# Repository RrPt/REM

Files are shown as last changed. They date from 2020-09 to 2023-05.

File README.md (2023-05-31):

# REM
Rainers Energy Measurement

**Short englisch description:**  
*REM is an AC Energy Monitor based on the Analog Devices IC ADE7816 and a 
ESP32 microcontroller. It consists of one controlling module REM-C and one
to eight measuring modules REM-M, where each REM-M modul can measure up to 
12 different circuits. So totaly 96 circuits can be meassured.
Power data can be sent by MQTT or WebServer. The Webserver ist also used for configuration and calibration.*

*This project ist in german, to translate you can use a translator program like [here](https://translate.google.com/translate?hl=de&sl=auto&tl=en&u=https%3A%2F%2Fgithub.com%2FRrPt%2FREM)*

**Kurzbeschreibung:**  
REM ist ein Energiemonitor der auf dem Analog Device IC ADE7816 und einem Mikrocontroller ESP32 basiert.
Er besteht aus einem Kontrollermodul REM-C und einem bis acht Messmodulen REM-M. 
Jedes REM-M Modul kann 12 verschiedene Leistungskreise messen, so dass insgesamt bis zu 
96 Schaltkreise gemessen werden können.
Die Leistungsdaten können per MQTT versendet oder über einen Webserver abgefragt werden.
Der Webserver wird auch für die Konfiguration und die Kalibrierung verwendet.

Die Komponenten werden normalerweise in der Hausverteilung installiert und können dann die Leistung von z.B. einzelnen Zimmern erfassen.

Wine ausführliche Beschreibung ist im [Wiki](../../wiki/Home) zu finden.
## Übersicht
Das System besteht aus mehreren Hutschinenkomponenten, die über den REM-Bus miteinander verbunden sind
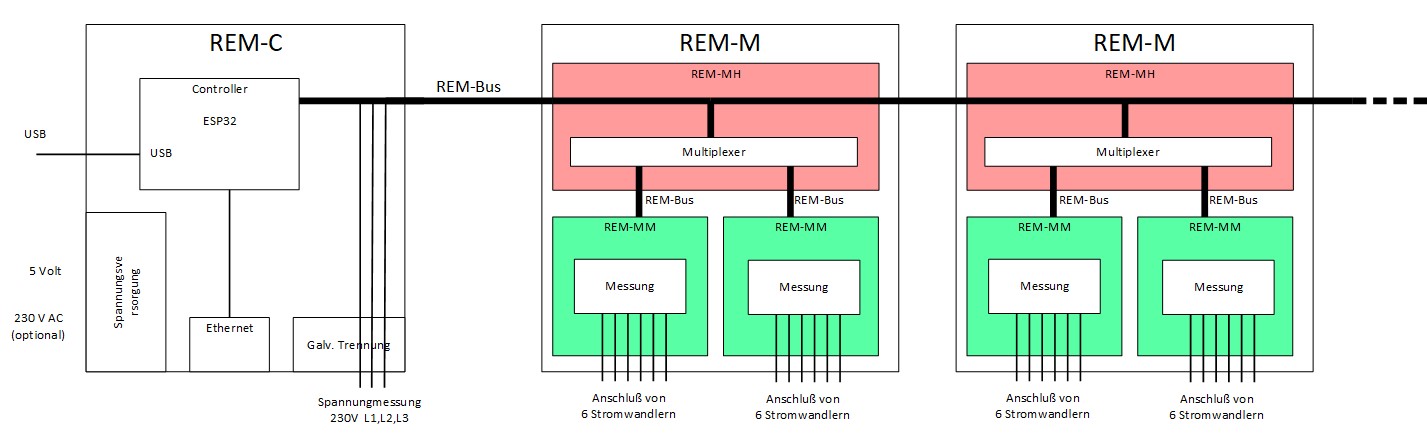
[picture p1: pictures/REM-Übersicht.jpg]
REM Übersicht


## [REM-C](../../wiki/REM-C) 
Das REM-C Modul enthält den Controller. Dieser fragt alle Messwerte über den 
REM-Bus von den einzelnen REM-M Modulen ab und stellt diesen über den 
Ethernetanschluß zur Verfügung. Die geschieht per MQTT und einen Webserver.
Über den Webserver erfolgt auch die Kalibrierung.

An das REM-C Modul werden auch die drei Phasen der Spannungssignale angeschlossen,
diese werden galvanisch getrennt und über den REM-Bus den einzelnen REM-M Modulen
 zur Verfügung gestellt.

Es können bis zu 8 REM-M Module mit je 12 Kanälen angeschlossen werden, 
insgesamt also bis zu 96 Kanäle.

Für die Platine des REM-C Moduls stehen die KICAD Pläne, 
die 3D-Modelle der Gehäuse (SCAD) und 
die Controllersoftware in C++ (Arduino) zur Verfügung. 

## [REM-M](../../wiki/REM-M) 
### [REM-MH](https://github.com/RrPt/REM/wiki/REM-MH) 
Das REM-M Modul beinhaltet zum einen ein Verteilermodul REM-MH, 
welches den REM-BUS auf die 2 REM-MM Module aufteilt.
Auf diesem wird auch per Jumper die Adresse des REM-M Moduls eingestellt.
### [REM-MM](../../wiki/REM-MM) 
Jedes REM-M Modul beinhaltet 2 REM-MM Platinen, die für die eigentliche 
Messung zuständig sind.
An jede REM-MM Platine können 6 Stromsensoren angeschlossen werden, 
zusammen mit der über den REM-Bus gelieferten Spannung 
(Phase über Jumper für alle 6 Sensoren gleich einstellbar)
können so für alle 6 Kanäle die folgenden Energieparameter bestimmt werden:
 * Strom RMS
 * Leistung
 * Blindleistung
 
Pro REM-MM Platine:
 * Spannung RMS
 * Frequenz

Für die Platinen des REM-M Moduls stehen die KICAD Pläne und 
die 3D-Modelle der Gehäuse (SCAD) zur Verfügung. 

## Status
Das Projekt ist fertiggestellt und bei mir seit Anfang 2021 ununterbrochen ohne Probleme im Betrieb.

## Bilder

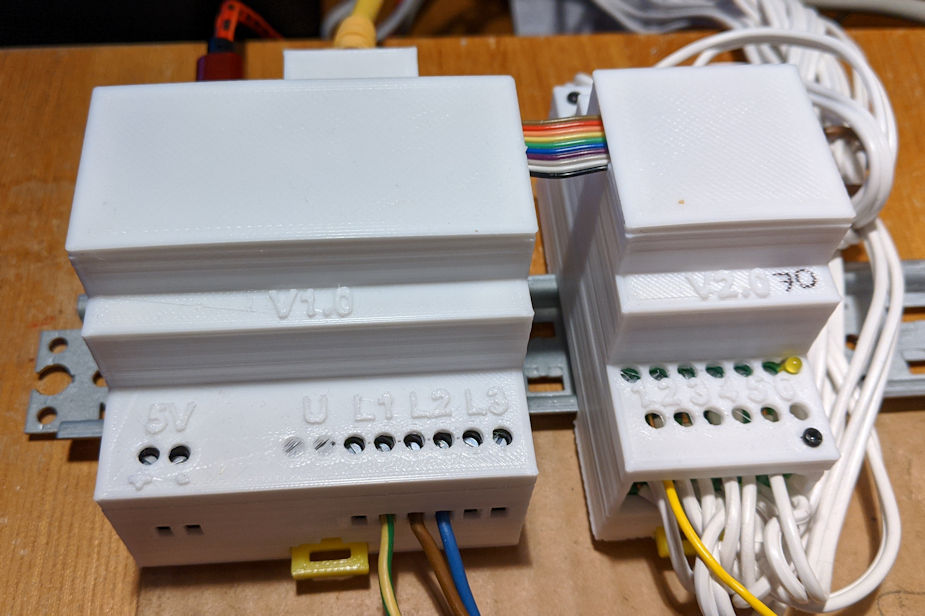
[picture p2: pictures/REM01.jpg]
REM01


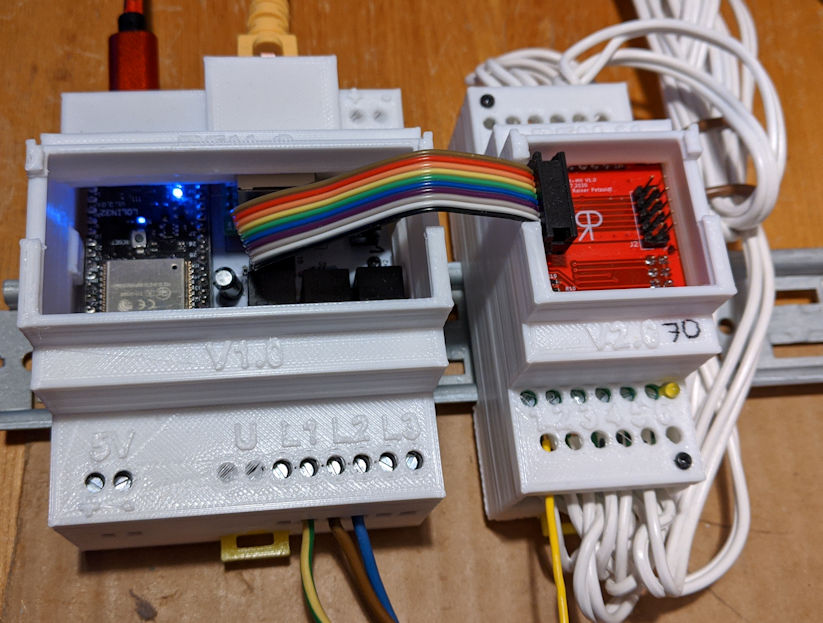
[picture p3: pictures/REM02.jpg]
REM02


## Stichwörter
 * ADE7816, Energy Metering IC
 * ESP32
 * TCA9548A
 * USR ES1
 * Leistungsmessung, Blindleistungsmessung, Spannungsmessung, Strommessung, RMS
 * Stromwandler, Current transformer, ZMPT107-1, CT1005
 * Energiemonitor

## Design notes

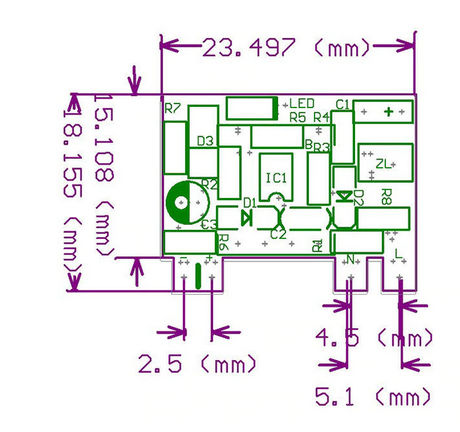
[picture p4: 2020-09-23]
REM-Platinen/3d/acad/Skizze.jpg

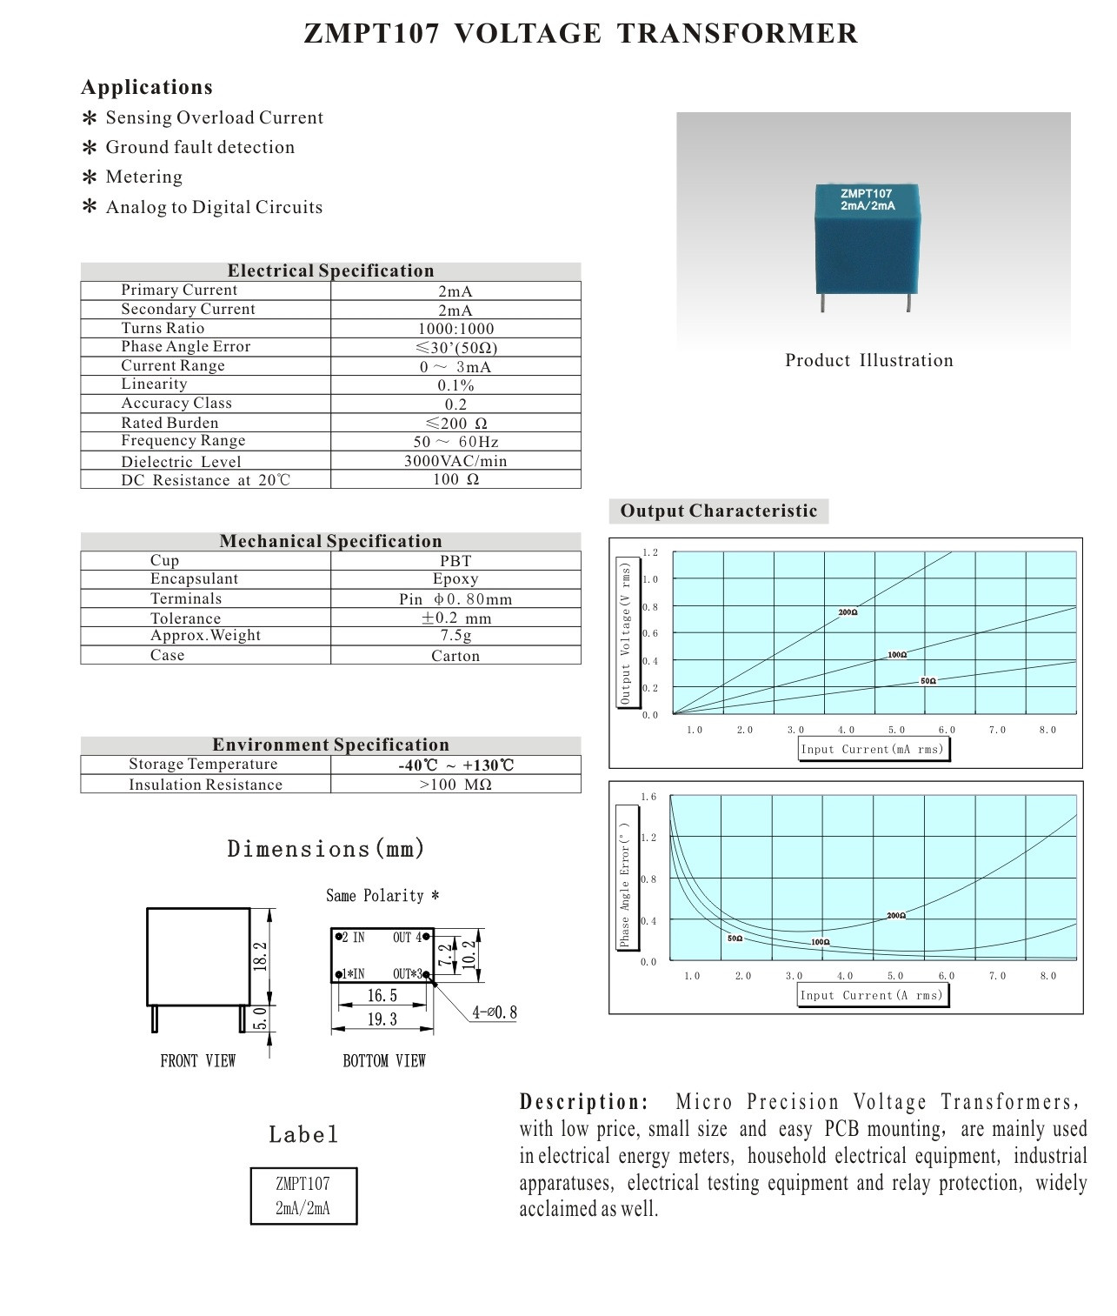
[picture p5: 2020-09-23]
REM-Platinen/Bauteile/ZMPT107.jpg

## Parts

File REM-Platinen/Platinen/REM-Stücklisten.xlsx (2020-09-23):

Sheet: REM-C
Reference | Quantity | Value | Footprint | Datasheet | Preis | Link | Lieferant | Summe
C1 C3 C4 C5 | 4 | 100n | Capacitor_SMD:C_0603_1608Metric | https://cdn-reichelt.de/documents/datenblatt/B300/KEM_C0XXX_Y5V_DB-EN.pdf | 0.02 | https://www.reichelt.de/vielschicht-kerko-100nf-25v-85-c-kem-y5v0603-100n-p207005.html | Reichelt | 0.08 €
C2 C6 | 2 | 10u | Capacitor_THT:CP_Radial_D5.0mm_P2.00mm | https://cdn-reichelt.de/documents/datenblatt/B300/KEM_C0XXX_X7R_DB-EN.pdf | 0.1 | https://www.reichelt.de/elko-radial-10-uf-50-v-105-c-low-esr-fr-a-10u-50-p200268.html | Reichelt | 0.20 €
J4 J3 J2 J1 J5 J6 | 6 | Conn_01x02 | REM:W237-102 | https://cdn-reichelt.de/documents/datenblatt/C100/AKL073%23RIA.pdf | 0.5 | https://www.reichelt.de/fahrstuhlklemme-2-pol-4-mm-rm-5-08-akl-073-02-p36620.html | Reichelt | 3.00 €
J7 | 1 | Conn_02x05_Odd_Even | REM:PinHeader_2x05_P2.54mm_Vertical_mit_Stecker | https://cdn-reichelt.de/documents/datenblatt/C140/DS_MPE_087.pdf | 0.23 | https://www.reichelt.de/stiftleisten-2-54-mm-2x05-gerade-mpe-087-2-010-p119895.html | Reichelt | 0.23 €
PS1 | 1 | AC-DC-Wandler | REM:AC-DC_Wandler |  | 1.31 | https://de.aliexpress.com/item/33030791040.html | AliExpress | 1.31 €
R1 R3 R2 | 3 | 220k | Resistor_THT:R_Axial_DIN0414_L11.9mm_D4.5mm_P15.24mm_Horizontal | https://www.reichelt.de/index.html?ACTION=7&LA=3&OPEN=0&INDEX=0&FILENAME=B300%2FNHMBX-SMA_DATA_EN.pdf | 0.13 | https://www.reichelt.de/duennschichtwiderstand-axial-1-w-220-kohm-1-vi-mbe04140c2203-p233820.html | Reichelt | 0.39 €
R6 R5 R4 | 3 | 330 | Resistor_THT:R_Axial_DIN0207_L6.3mm_D2.5mm_P7.62mm_Horizontal | https://cdn-reichelt.de/documents/datenblatt/B300/NGMBX-SMA_DATA_E.pdf | 0.04 | https://www.reichelt.de/duennschichtwiderstand-axial-0-6-w-330-ohm-1-vi-mbb02070c3300-p233724.html | Reichelt | 0.12 €
T3 T2 T1 | 3 | ZMPT107-1 | REM:ZMPT107 | D:\Daten\Petzoldt\Rainer\Entwicklung\REM\Bauteile\ZMPT101B specification.pdf | 0.95 | https://de.aliexpress.com/item/10000007567815.html | AliExpress | 2.85 €
U1 | 1 | Lolin32 | REM:Lolin32 |  | 3.61 | https://de.aliexpress.com/item/4000340140634.html | AliExpress | 3.61 €
U2 | 1 | USR-ES1 | REM:USR-ES1 | D:\Daten\Petzoldt\Rainer\Entwicklung\Dokumentation\Bauteiledokumentation\Adapter\USR-ES1-EN-V1.0.pdf | 3.33 | https://de.aliexpress.com/item/4000923964703.html | AliExpress | 3.33 €
ESP32-Fassung | 1 | 16 | 16 | https://cdn-reichelt.de/documents/datenblatt/C140/DATENBLATT_B01-EBLG70_DB.pdf | 0.84 | https://www.reichelt.de/buchsenleiste-16-pol-gerade-rm-2-54-h-7-0-mm-bl-1x16g7-2-54-p180555.html | Reichelt | 0.84 €
ESP32-Fassung | 1 | 20 | 20 | https://cdn-reichelt.de/documents/datenblatt/C140/DATENBLATT_B01-EBLG70_DB.pdf | 0.99 | https://www.reichelt.de/20pol-buchsenleiste-gerade-rm-2-54-h-7-0mm-bl-1x20g7-2-54-p73677.html | Reichelt | 0.99 €
USR-Fassung | 2 | 6 | 1 x 6 | https://cdn-reichelt.de/documents/datenblatt/C140/DATENBLATT_B01-EBLG70_DB.pdf | 0.31 | https://www.reichelt.de/buchsenleiste-6-pol-gerade-rm-2-54-h-7-0-mm-bl-1x06g7-2-54-p180550.html | Reichelt | 0.62 €
 | 1 | 2 x 5 | IDC-Federleiste 10P | https://cdn-reichelt.de/documents/datenblatt/C150/RND_205-00682_ENG_TDS.pdf | 0.25 € | https://www.reichelt.de/idc-federleiste-10p-rnd-205-00682-p222827.html | Reichelt | 0.25 €
 |  |  |  |  |  | Summe |  | 17.82 €

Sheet: REM-MH
Reference | Quantity | Value | Footprint | Datasheet | Preis | Link | Lieferant | Summe
C7 C1 | 2 | 10u | Capacitor_SMD:C_1206_3216Metric | https://cdn-reichelt.de/documents/datenblatt/B300/KEM_C0XXX_X7R_DB-EN.pdf | 0.13 | https://www.reichelt.de/vielschicht-kerko-10-f-16v-125-c-kem-x7r1206-10u-p207163.html? | Reichelt | 0.26 €
C8 C2 | 2 | 220n | Capacitor_SMD:C_0603_1608Metric | https://cdn-reichelt.de/documents/datenblatt/A900/RND_1398195_CAP_0603_X7R_ENG_TDS.pdf | 0.02 | https://www.reichelt.de/smd-kerko-0603-220-nf-16-v-10-mlcc-rnd-150sh18b224-p225500.html | Reichelt | 0.04 €
J3 J4 J1 J2 | 4 | Conn_02x05_Odd_Even | REM:PinHeader_2x05_P2.54mm_Vertical_mit_Stecker | https://cdn-reichelt.de/documents/datenblatt/C140/DS_MPE_087.pdf | 0.23 € | https://www.reichelt.de/stiftleisten-2-54-mm-2x05-gerade-mpe-087-2-010-p119895.html | Reichelt | 0.92 €
J5 | 1 | Conn_02x03_Odd_Even | Connector_PinHeader_2.54mm:PinHeader_2x03_P2.54mm_Vertical | https://cdn-reichelt.de/documents/datenblatt/C140/RND_205-00634_DB_EN.pdf | 0.03 | https://www.reichelt.de/rnd-stiftleiste-6-pol-rm-2-54-mm-rnd-205-00634-p208860.html?&trstct=pol_0 | Reichelt | 0.03 €
R1 R2 R3 R4 R6 R7 R8 R5 | 8 | 10k | Resistor_SMD:R_0603_1608Metric | https://cdn-reichelt.de/documents/datenblatt/B300/RND_SMD_0603_RESISTOR_2017.pdf | 0.02 | https://www.reichelt.de/smd-widerstand-0603-10-kohm-100-mw-1-vis-crcw060310k-p238029.html | Reichelt | 0.16 €
U1 | 1 | TCA9548APWR | Package_SO:TSSOP-24_4.4x7.8mm_P0.65mm | http://www.ti.com/lit/ds/symlink/tca9548a.pdf | 1.37 | https://www.digikey.de/product-detail/de/texas-instruments/TCA9548APWR/296-34905-1-ND/3615448 | DigiKey | 1.37 €
 | 4 | 2 x 5 | IDC-Federleiste 10P | https://cdn-reichelt.de/documents/datenblatt/C150/RND_205-00682_ENG_TDS.pdf | 0.25 € | https://www.reichelt.de/idc-federleiste-10p-rnd-205-00682-p222827.html | Reichelt | 1.00 €
 |  |  |  |  |  | Summe |  | 3.78 €

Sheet: REM-MM
Reference | Quantity | Value | Footprint | Datasheet | Preis | Link | Lieferant | Summe
C11 C17 C9 C8 | 4 | 220n | Capacitor_SMD:C_0603_1608Metric | https://cdn-reichelt.de/documents/datenblatt/A900/RND_1398195_CAP_0603_X7R_ENG_TDS.pdf | 0.02 € | https://www.reichelt.de/smd-kerko-0603-220-nf-25-v-10-mlcc-rnd-1500603x224-p226196.html | Reichelt | 0.08 €
C12 C10 C18 | 3 | 4.7u | Capacitor_SMD:C_1206_3216Metric | https://cdn-reichelt.de/documents/datenblatt/B300/RND_1206_ENG_TDS.pdf | 0.08 € | https://www.reichelt.de/smd-kerko-1206-4-7-f-50-v-10-mlcc-rnd-1501206b475k-p254230.html | Reichelt | 0.24 €
C13 C2 C3 C4 C5 C6 C1 | 7 | 22n | Capacitor_SMD:C_0603_1608Metric | ~ | 0.02 € | https://www.reichelt.de/smd-vielschicht-keramikkondensator-22n-10-x7r-g0603-22n-p31871.html | Reichelt | 0.14 €
C14 | 1 | 1u | Capacitor_SMD:C_0603_1608Metric | https://cdn-reichelt.de/documents/datenblatt/A900/RND_1407500_CAP_0603_NP0_ENG_TDS.pdf | 0.02 € | https://www.reichelt.de/smd-kerko-0603-6-8-pf-16-v-10-mlcc-rnd-150mt18n6r81-p225486.html | Reichelt | 0.02 €
C15 C16 | 2 | 20p | Capacitor_SMD:C_0603_1608Metric | https://cdn-reichelt.de/documents/datenblatt/B300/KEM_C0XXX_C0G_DB-EN.pdf | 0.03 € | https://www.reichelt.de/vielschicht-kerko-20pf-50v-125-c-kem-c0g0603-20p-p206942.html | Reichelt | 0.06 €
C7 | 1 | 10u | Capacitor_SMD:C_1206_3216Metric | https://cdn-reichelt.de/documents/datenblatt/B300/KEM_C0XXX_X7R_DB-EN.pdf | 0.13 € | https://www.reichelt.de/vielschicht-kerko-10-f-16v-125-c-kem-x7r1206-10u-p207163.html? | Reichelt | 0.13 €
J1 | 1 | Conn_02x05_Odd_Even | REM:PinHeader_2x05_P2.54mm_Vertical_mit_Stecker | https://cdn-reichelt.de/documents/datenblatt/C140/DS_MPE_087.pdf | 0.23 € | https://www.reichelt.de/stiftleisten-2-54-mm-2x05-gerade-mpe-087-2-010-p119895.html | Reichelt | 0.23 €
J2 | 1 | Conn_02x03_Odd_Even | Connector_PinHeader_2.54mm:PinHeader_2x03_P2.54mm_Vertical | https://cdn-reichelt.de/documents/datenblatt/C140/RND_205-00634_DB_EN.pdf | 0.03 € | https://www.reichelt.de/rnd-stiftleiste-6-pol-rm-2-54-mm-rnd-205-00634-p208860.html?&trstct=pol_0 | Reichelt | 0.03 €
J3 | 1 | DG127A 5,08-6 | REM:pxc_1726189_05_MKKDSN-1-5-6-5-08 | https://www.reichelt.de/index.html?ACTION=7&LA=3&OPEN=0&INDEX=0&FILENAME=C151%2FDG127A.pdf | 0.99 € | https://www.reichelt.de/leiterplattenklemme-6-polig-rm-5-08-mm-dg127a-5-08-6-p276159.html? | Reichelt | 0.99 €
R11 R12 R13 R14 R15 R16 | 6 | 47 | Resistor_SMD:R_0603_1608Metric | https://cdn-reichelt.de/documents/datenblatt/B400/DS_PAN_SERIE_ERA.pdf | 0.25 € | https://www.reichelt.de/smd-widerstand-0603-47-0-ohm-100-mw-0-1-spr-0603-47-0-p123052.html | Reichelt | 1.50 €
R7 R1 R2 R3 R4 R5 R6 | 7 | 1k | Resistor_SMD:R_0603_1608Metric | https://cdn-reichelt.de/documents/datenblatt/B300/RND_SMD_0603_RESISTOR_2017.pdf | 0.02 € | https://www.reichelt.de/smd-widerstand-0603-1-0-kohm-100-mw-1-rnd-0603-1-1-0k-p183054.html | Reichelt | 0.14 €
R8 | 1 | 4.7M | Resistor_SMD:R_0603_1608Metric | https://cdn-reichelt.de/documents/datenblatt/B300/RND_SMD_0603_RESISTOR_2017.pdf | 0.02 € | https://www.reichelt.de/smd-widerstand-0603-4-7-mohm-100-mw-1-rnd-0603-1-4-7m-p183143.html | Reichelt | 0.02 €
R9 | 1 | 10k | Resistor_SMD:R_0603_1608Metric | https://cdn-reichelt.de/documents/datenblatt/B300/RND_SMD_0603_RESISTOR_2017.pdf | 0.02 € | https://www.reichelt.de/smd-widerstand-0603-10-kohm-100-mw-1-vis-crcw060310k-p238029.html | Reichelt | 0.02 €
U1 | 1 | ADE7816ACPZ | REM:QFN50P600X600X80-41N | https://www.analog.com/media/en/technical-documentation/data-sheets/ADE7816.pdf | 10.20 € | https://www.digikey.de/product-detail/de/analog-devices-inc/ADE7816ACPZ/ADE7816ACPZ-ND/3131705 | DigiKey | 10.20 €
U2 | 1 | MCP23008-xSO | Package_SO:SOIC-18W_7.5x11.6mm_P1.27mm | http://ww1.microchip.com/downloads/en/DeviceDoc/MCP23008-MCP23S08-Data-Sheet-20001919F.pdf | 0.94 € | https://www.digikey.de/product-detail/de/microchip-technology/MCP23008T-E-SO/MCP23008T-E-SOCT-ND/5358243 | DigiKey | 0.94 €
Y1 | 1 | 16.384MHz | Crystal:Crystal_SMD_2520-4Pin_2.5x2.0mm | https://support.epson.biz/td/api/doc_check.php?dl=brief_FA-238&lang=en | 0.30 € | https://www.digikey.de/products/de/crystals-oscillators-resonators/crystals/171?k=quarz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 | DigiKey | 0.30 €
 | 1 | 2 x 5 | IDC-Federleiste 10P | https://cdn-reichelt.de/documents/datenblatt/C150/RND_205-00682_ENG_TDS.pdf | 0.25 € | https://www.reichelt.de/idc-federleiste-10p-rnd-205-00682-p222827.html | Reichelt | 0.25 €
 |  |  |  |  |  | Summe |  | 15.29 €

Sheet: Reichelt
 |  |  |  |  | 3 | 5 | 10 |  |  |  |  |  | Nachbestellung 9.8.20
Reference | Value | Einzelpreis | Link | Lieferant | REM-C | REM-MH | REM-MM | Anzahl | Preis | Bestellmenge | Preis | Anz Reserve | Bestellmenge | Preis | Anz Reserve | Bestand 9.8
C | 100n | 0.02 € | https://www.reichelt.de/vielschicht-kerko-100nf-25v-85-c-kem-y5v0603-100n-p207005.html | Reichelt | 4 |  |  | 12 | 0.24 € | 10 | 0.20 € | -2 | 50 | 1.00 € | 48 | 6
C | 10u | 0.10 € | https://www.reichelt.de/elko-radial-10-uf-50-v-105-c-low-esr-fr-a-10u-50-p200268.html | Reichelt | 2 |  |  | 6 | 0.60 € | 5 | 0.50 € | -1 | 10 | 1.00 € | 9 | 3
C | 10u | 0.13 € | https://www.reichelt.de/vielschicht-kerko-10-f-16v-125-c-kem-x7r1206-10u-p207163.html? | Reichelt |  | 2 | 1 | 20 | 2.60 € | 20 | 2.60 € | 0 | 10 | 1.30 € | 10 | 14
C | 1u | 0.08 € | https://www.reichelt.de/smd-vielschichtkondensator-g0603-1-0-f-16v-x7r-g0603-1-0-16-p89719.html | Reichelt | 1 |  | 1 | 13 | 1.04 € | 20 | 1.60 € | 7 | 20 | 1.60 € | 27 | 15
C | 20p | 0.03 € | https://www.reichelt.de/vielschicht-kerko-20pf-50v-125-c-kem-c0g0603-20p-p206942.html | Reichelt |  |  | 2 | 20 | 0.60 € | 20 | 0.60 € | 0 | 20 | 0.60 € | 20 | 12
C | 220n | 0.02 € | https://www.reichelt.de/smd-kerko-0603-220nf-10v-10-mlcc-ft-cap-x7r-0603fcc-220n-p193817.html | Reichelt |  | 2 | 4 | 50 | 1.00 € | 50 | 1.00 € | 0 | 50 | 1.00 € | 50 | 36
C | 22n | 0.02 € | https://www.reichelt.de/smd-vielschicht-keramikkondensator-22n-10-x7r-g0603-22n-p31871.html | Reichelt |  |  | 7 | 70 | 1.40 € | 70 | 1.40 € | 0 | 50 | 1.00 € | 50 | 36
C | 4.7u | 0.08 € | https://www.reichelt.de/smd-kerko-1206-4-7-f-50-v-10-mlcc-rnd-1501206b475k-p254230.html | Reichelt |  |  | 3 | 30 | 2.40 € | 30 | 2.40 € | 0 | 20 | 1.60 € | 20 | 18
ESP32-Fassung | 16 | 0.84 € | https://www.reichelt.de/buchsenleiste-16-pol-gerade-rm-2-54-h-7-0-mm-bl-1x16g7-2-54-p180555.html | Reichelt | 1 |  |  | 3 | 2.52 € | 5 | 4.20 € | 2 | 3 | 2.52 € | 5 | 4
ESP32-Fassung | 20 | 0.99 € | https://www.reichelt.de/20pol-buchsenleiste-gerade-rm-2-54-h-7-0mm-bl-1x20g7-2-54-p73677.html | Reichelt | 1 |  |  | 3 | 2.97 € | 5 | 4.95 € | 2 | 3 | 2.97 € | 5 | 4
J3 | DG127A 5,08-6 | 0.99 € | https://www.reichelt.de/leiterplattenklemme-6-polig-rm-5-08-mm-dg127a-5-08-6-p276159.html? | Reichelt |  |  | 2 | 20 | 19.80 € | 10 | 9.90 € | -10 | 15 | 14.85 € | 5 | 2
J4 J3 J2 J1 J5 J6 | AKL 073-02 | 0.50 € | https://www.reichelt.de/fahrstuhlklemme-2-pol-4-mm-rm-5-08-akl-073-02-p36620.html | Reichelt | 6 |  |  | 18 | 9.00 € | 15 | 7.50 € | -3 | 10 | 5.00 € | 7 | 11
J5 | Conn_02x03_Odd_Even | 0.03 € | https://www.reichelt.de/rnd-stiftleiste-6-pol-rm-2-54-mm-rnd-205-00634-p208860.html?&trstct=pol_0 | Reichelt |  | 1 | 1 | 15 | 0.45 € | 15 | 0.45 € | 0 | 10 | 0.30 € | 10 | 10
J7 | Conn_02x05_Odd_Even | 0.03 € | https://www.reichelt.de/rnd-stiftleiste-10-pol-rm-2-54-mm-rnd-205-00636-p208862.html | Reichelt | 1 | 4 | 1 | 33 | 0.99 € | 30 | 0.90 € | -3 | 20 | 0.60 € | 17 | 21
 | Conn_02x06_Odd_Even | 0.04 € | https://www.reichelt.de/rnd-stiftleiste-12-pol-rm-2-54-mm-rnd-205-00637-p208863.html | Reichelt | 1 |  |  | 3 | 0.12 € | 0 | 0.00 € | -3 | 10 | 0.40 € | 7 | 0
R | 47 | 0.25 € | https://www.reichelt.de/smd-widerstand-0603-47-0-ohm-100-mw-0-1-spr-0603-47-0-p123052.html | Reichelt |  |  | 6 | 60 | 15.00 € | 50 | 12.50 € | -10 | 20 | 5.00 € | 10 | 24
R | 330 | 0.04 € | https://www.reichelt.de/duennschichtwiderstand-axial-0-6-w-330-ohm-1-vi-mbb02070c3300-p233724.html | Reichelt | 3 |  |  | 9 | 0.36 € | 10 | 0.40 € | 1 | 0 | 0.00 € | 1 | 7
R | 10k | 0.02 € | https://www.reichelt.de/smd-widerstand-0603-10-kohm-100-mw-1-vis-crcw060310k-p238029.html | Reichelt |  | 20 | 1 | 110 | 2.20 € | 50 | 1.00 € | -60 | 100 | 2.00 € | 40 | 24
R | 1k | 0.02 € | https://www.reichelt.de/smd-widerstand-0603-1-0-kohm-100-mw-1-rnd-0603-1-1-0k-p183054.html | Reichelt |  |  | 8 | 80 | 1.60 € | 100 | 2.00 € | 20 | 0 | 0.00 € | 20 | 67
R | 220k | 0.13 € | https://www.reichelt.de/duennschichtwiderstand-axial-1-w-220-kohm-1-vi-mbe04140c2203-p233820.html | Reichelt | 3 |  |  | 9 | 1.17 € | 10 | 1.30 € | 1 | 0 | 0.00 € | 1 | 7
R | 100k | 0.02 € | https://www.reichelt.de/smd-widerstand-0603-100-kohm-100-mw-1-rnd-0603-1-100k-p183102.html | Reichelt | 1 |  |  | 3 | 0.06 € | 0 | 0.00 € | -3 | 100 | 2.00 € | 97 | 0
R | 4.7M | 0.02 € | https://www.reichelt.de/smd-widerstand-0603-4-7-mohm-100-mw-1-rnd-0603-1-4-7m-p183143.html | Reichelt |  |  | 1 | 10 | 0.20 € | 10 | 0.20 € | 0 | 0 | 0.00 € | 0 | 6
USR-Fassung | 6 | 0.31 € | https://www.reichelt.de/buchsenleiste-6-pol-gerade-rm-2-54-h-7-0-mm-bl-1x06g7-2-54-p180550.html | Reichelt | 2 |  |  | 6 | 1.86 € | 10 | 3.10 € | 4 | 0 | 0.00 € | 4 | 8
 | 2 x 5 Federleste z. Crimpen | 0.15 € | https://www.reichelt.de/idc-federleiste-10p-rnd-205-00682-p222827.html | Reichelt | 1 | 4 | 1 | 33 | 4.95 € | 30 | 4.50 € | -3 | 20 | 3.00 € | 17 | 22
 | 2 x 6 Federleste z. Crimpen | 0.63 € | https://www.reichelt.de/idc-federleiste-12p-rnd-205-00683-p222828.html | Reichelt | 1 |  |  | 3 | 1.89 € | 0 | 0.00 € | -3 | 5 | 3.15 € | 2 | 0
 |  |  |  |  |  |  |  |  | 75.02 € |  | 63.20 € |  |  | 50.89 €
 | TCA9548A Breakout |  |  |  |  |  |  |  |  |  | 8.30 €
 | Imbusschlüssel Zoll |  |  |  |  |  |  |  |  |  | 5.00 €
 | MCP23009 |  |  |  |  |  |  |  |  |  | 2.40 €
 |  |  |  |  |  |  |  |  |  |  | 78.90 €

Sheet: Allg
Reference | Quantity | Value | Footprint | Datasheet | Preis | Link | Lieferant | Summe | Bemerkung
REM-MM | 8 |  |  |  | 3.85 € |  |  | 30.80 €
REM-MH | 4 |  |  |  | 2.41 € |  |  | 9.64 €
REM-C | 2 |  |  |  | 7.97 € |  |  | 15.94 €
 |  |  |  |  |  |  |  | 16.00 €
 |  |  |  |  |  | Summe |  | 72.38 €

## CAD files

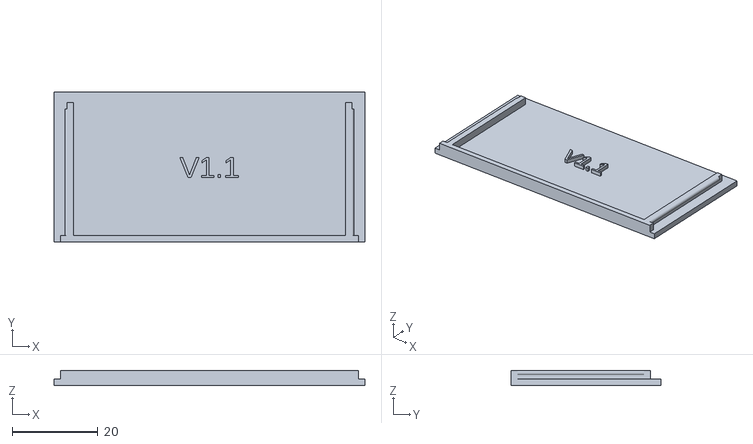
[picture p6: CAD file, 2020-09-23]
Gehaeuse/REM-C/REM-C-Deckel_V1.1.stl
72.5 x 35.0 x 3.50

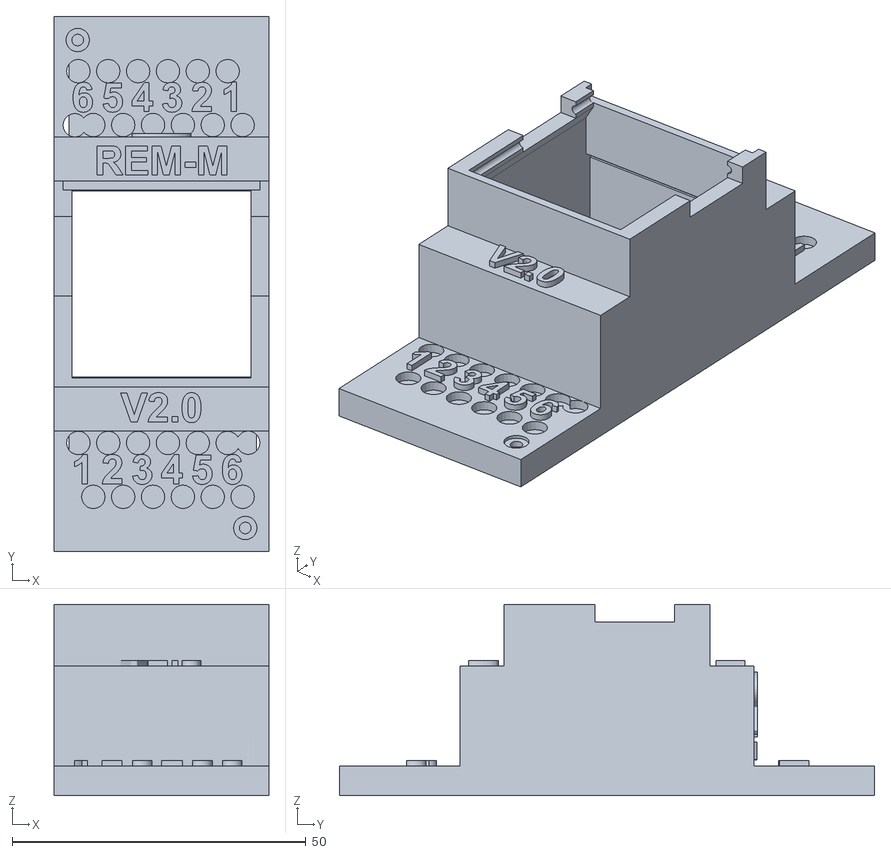
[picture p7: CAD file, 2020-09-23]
Gehaeuse/REM-M/REM-M-Oberteil_V2.0.stl
36.5 x 91.0 x 32.5

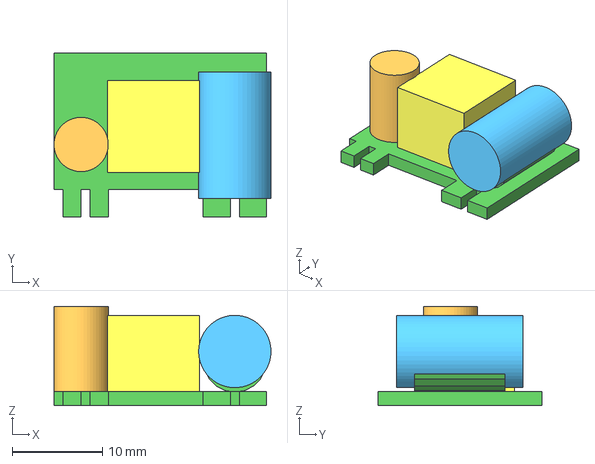
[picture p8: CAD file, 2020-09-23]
REM-Platinen/3d/acad/acdc.step
24.0 x 18.1 x 11.0 mm

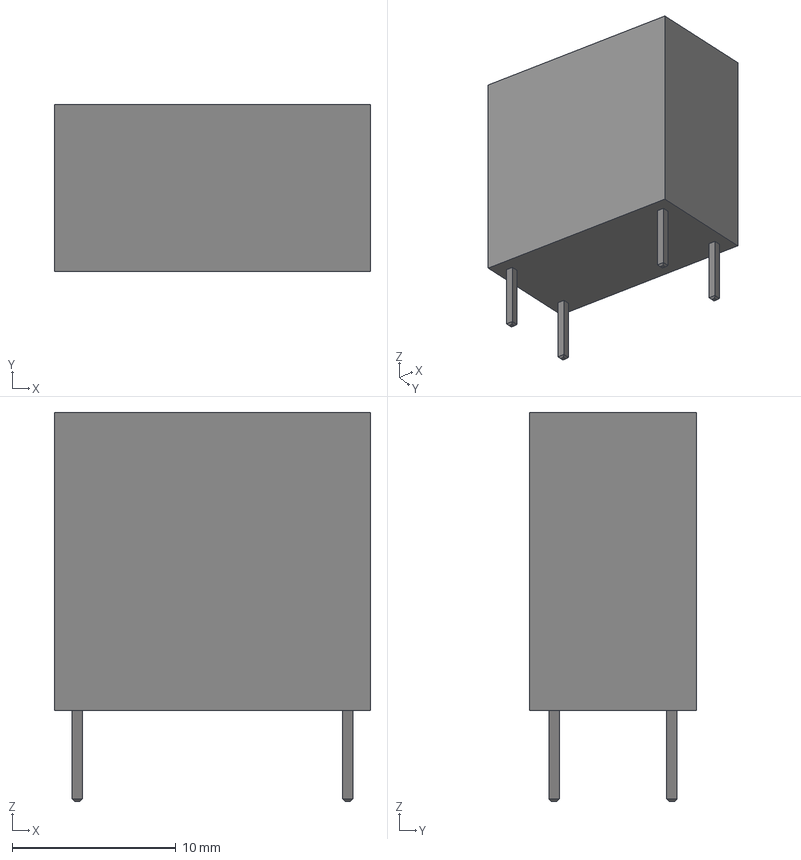
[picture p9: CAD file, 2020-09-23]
REM-Platinen/3d/ZMPT107.FCStd
19.3 x 10.2 x 23.7 mm
PinHeader_1x01_P254mm_Vertical
PinHeader_1x01_P254mm_Vertical001
PinHeader_1x01_P254mm_Vertical002
PinHeader_1x01_P254mm_Vertical003

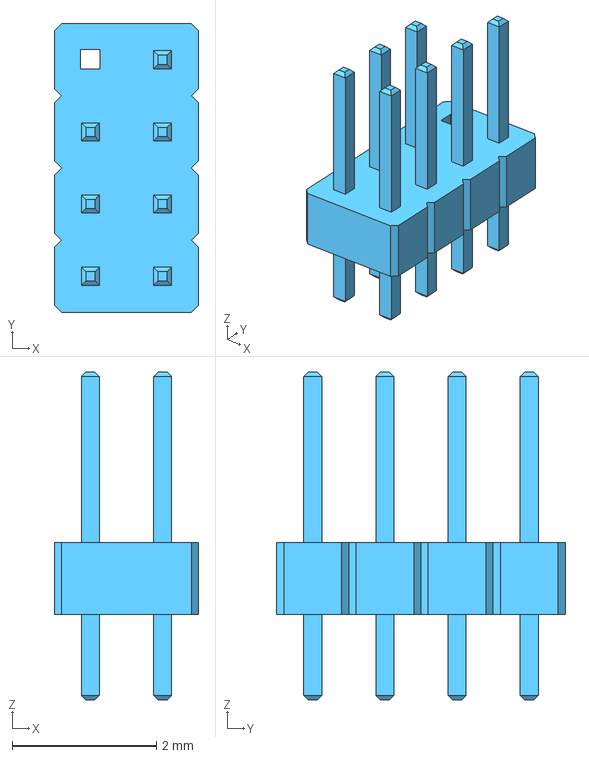
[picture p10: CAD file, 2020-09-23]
REM-Platinen/Platinen/modules/3dpackages/PinHead7.step
2.00 x 4.00 x 4.54 mm

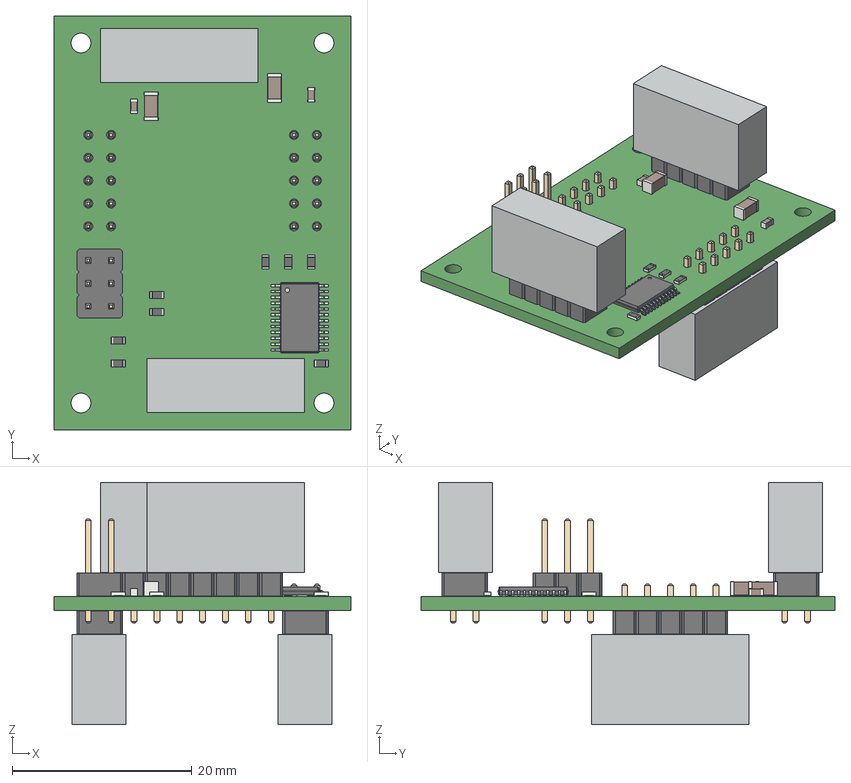
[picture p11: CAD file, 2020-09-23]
REM-Platinen/Platinen/REM-MH_mit_Stecker.step
33.0 x 46.0 x 26.9 mm

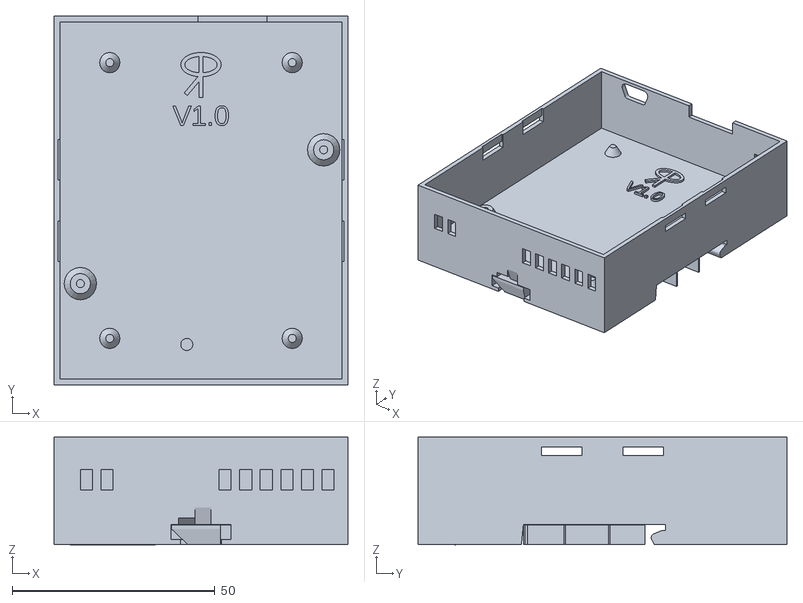
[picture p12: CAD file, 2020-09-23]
Gehaeuse/REM-C/REM-C-Unterteil_V1.0.stl
72.5 x 91.0 x 26.6

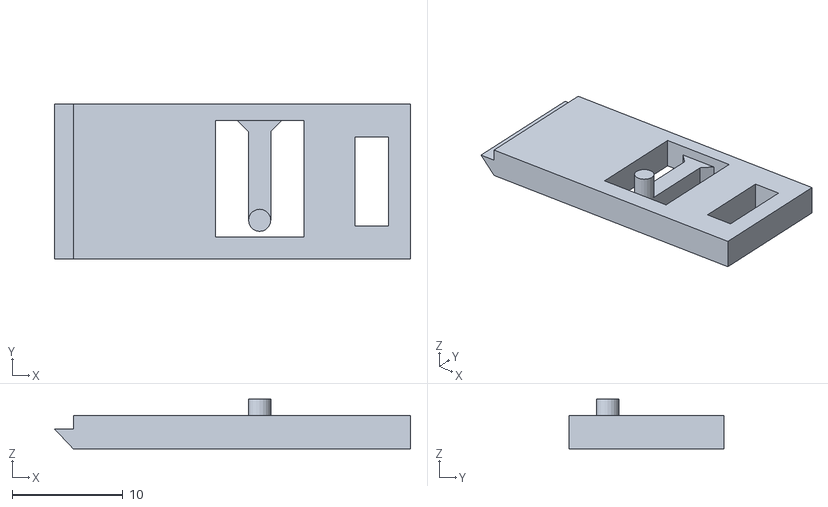
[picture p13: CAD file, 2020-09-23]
Gehaeuse/REM-M/Schnapper.stl
32.1 x 14.0 x 4.50

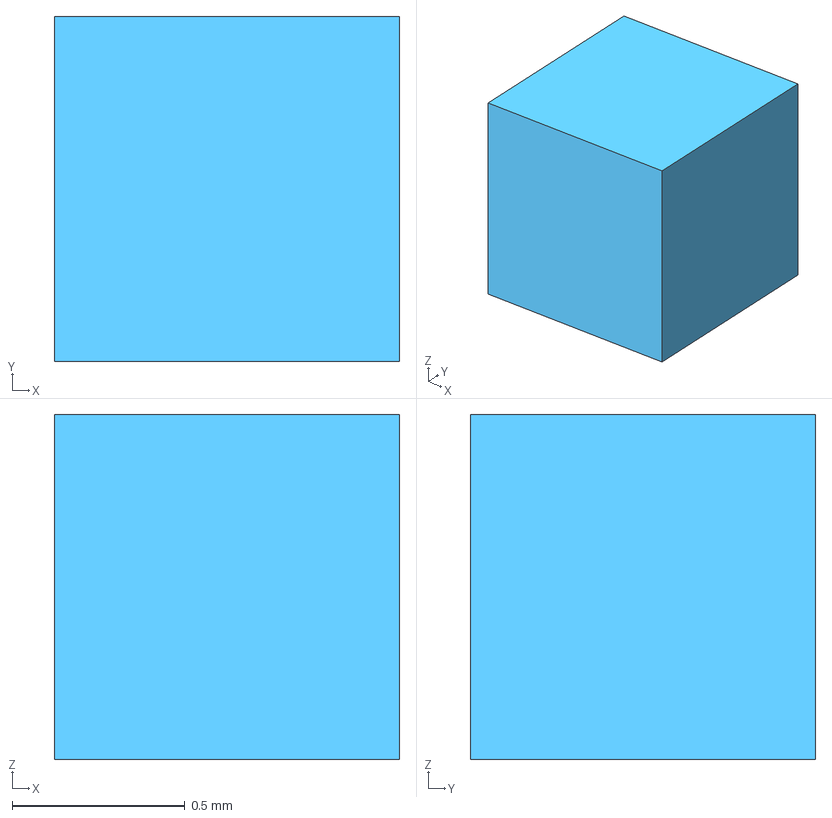
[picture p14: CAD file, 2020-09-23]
REM-Platinen/Platinen/modules/3dpackages/Box.step
1.00 x 1.00 x 1.00 mm

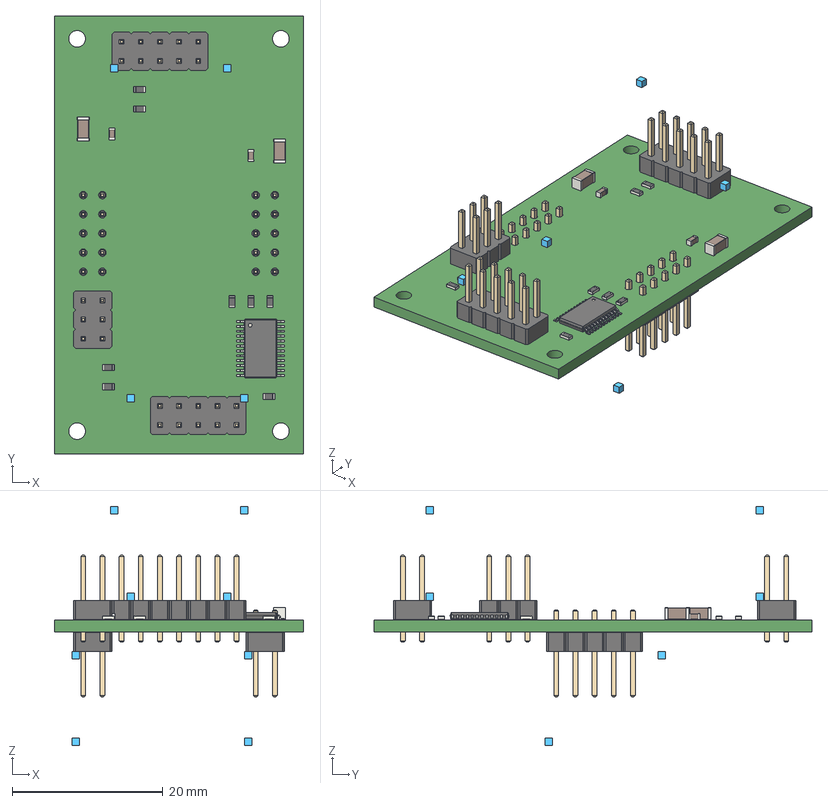
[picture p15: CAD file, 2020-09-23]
REM-Platinen/Platinen/REM-MH1.step
33.0 x 58.0 x 31.7 mm

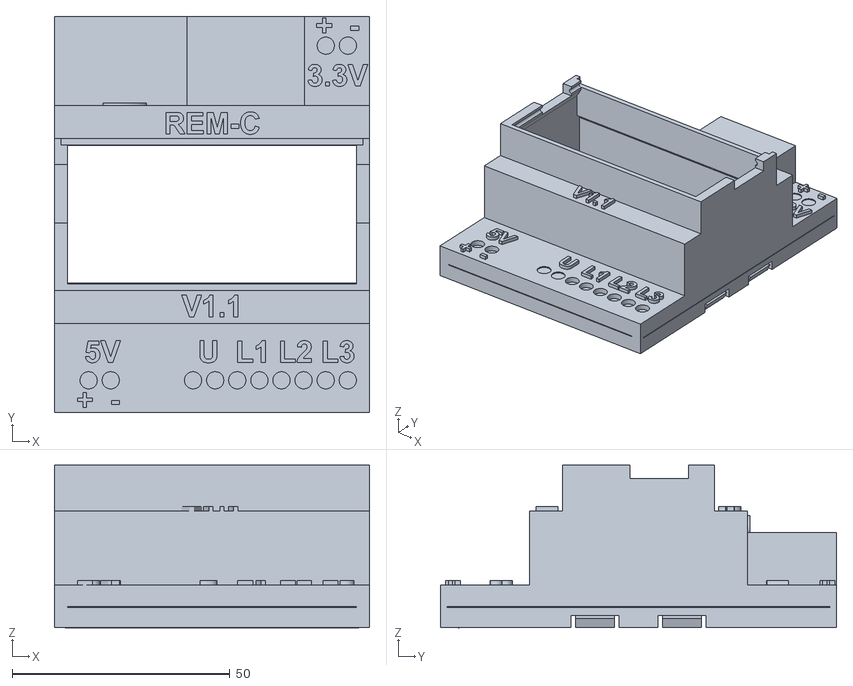
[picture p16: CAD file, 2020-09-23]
Gehaeuse/REM-C/REM-C-Oberteil_V1.1.stl
72.5 x 91.0 x 37.4

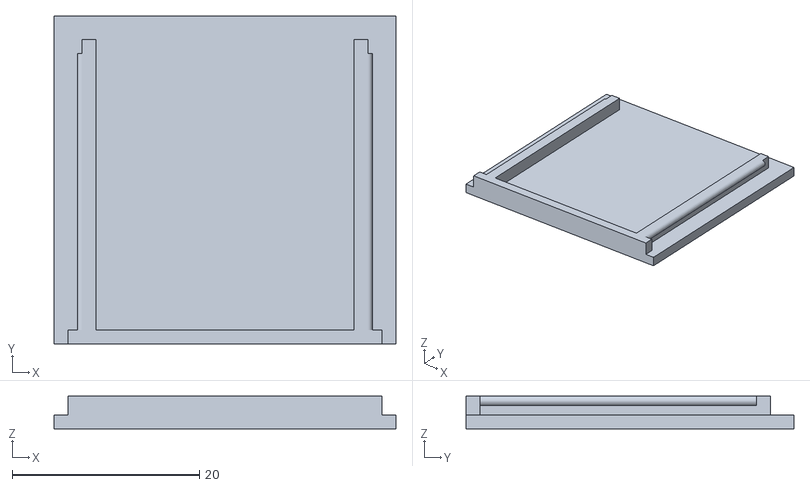
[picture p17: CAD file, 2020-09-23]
Gehaeuse/REM-M/REM-M-Deckel_V1.0.stl
36.5 x 35.0 x 3.50

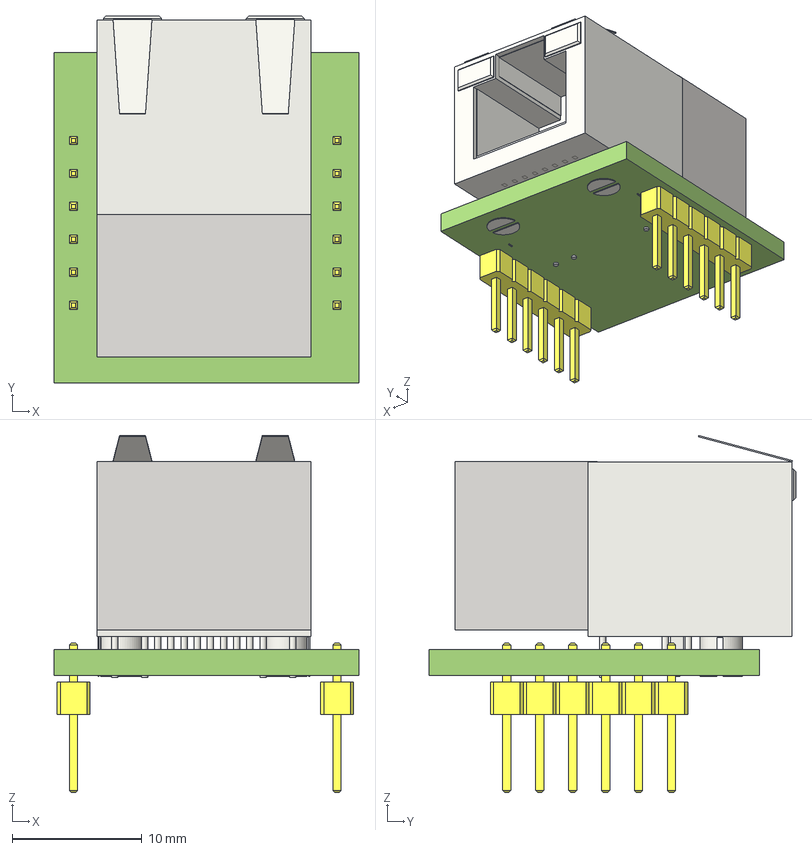
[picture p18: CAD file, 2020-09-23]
REM-Platinen/3d/USR-ES1.FCStd
23.5 x 28.3 x 27.5 mm
RJ45
Platine
Würfel
PinHeader_1x06_P254mm_Vertical
PinHeader_1x06_P254mm_Vertical001

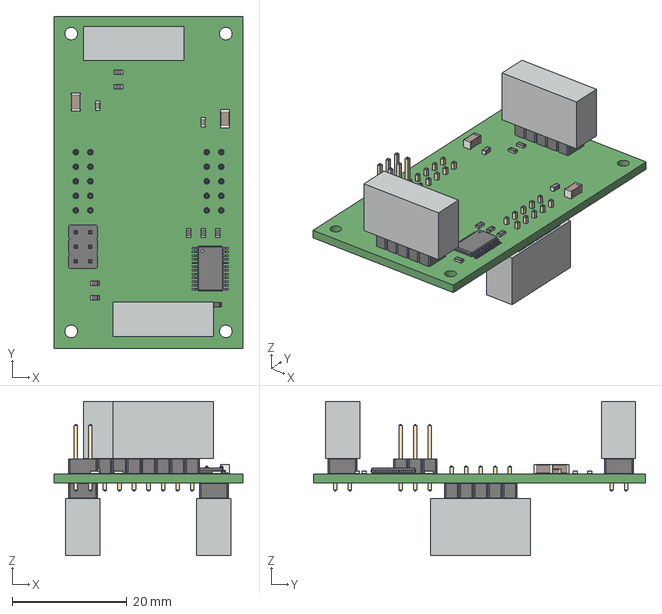
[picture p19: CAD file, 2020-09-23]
REM-Platinen/Platinen/REM-MH1_mit_Stecker.step
33.0 x 58.0 x 26.9 mm

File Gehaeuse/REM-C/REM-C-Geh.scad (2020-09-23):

//
//	Gerause für REM-C  / Din rail
//
//  by Rainer Petzoldt
//  basiert auf REM-M-Geh.scad V0.3.7
//  Slicen ohne Stützstruktur ;  4 Wandlinien ;  3 Obere- und untere Schichten
//     generateStuetzstruktur = true setzen

/* width in TE (=18mm) */
AnzTE = 4;   // [1:0.5:12]
/* select which part to show */
part = "Deckel" ; // [Unterteil, Oberteil, Deckel, Oberteil_mit_Deckel, Schnapper, all, assembled]
showPlatinen = false;
generateStuetzstruktur = true;

// *******************************************************************

/* [Hidden] */
deckelLift = 1*5;   // zieht module auseinander (Explosionszeichnung)
h1debug =  0*19;   // 0 = no debug  erniedrigt aussenwand um h1debug mm
Vers =  "V1.1";
TE = 18;	// Teilungseinheit
d = 1.5;   				// Wanddicke

breite = AnzTE * TE-0.5+1;  // Gesamtbreite aussen
tiefe = 91;				// Tiefe unterste Ebene
tiefe2 = 62-12;			// Tiefe mittlere Ebene
tiefe3 = 45-10;			// Tiefe mittlere Ebene

deltaH = 0*12;
h1 = 26.5+deltaH;				// Hoehe Unterteil gesamt aussen
h2 = 5;           // Aussparung fuer Schiene 
h3 = 5;         // Hoehe unterste Deckelschicht
h4 = 17-deltaH;          // Hoehe mittlere Deckelschicht
h5 = 22-10;          // Hoehe obere Deckelschicht
b1 = 28-2.5;
b2 = 0.5;
b3 = 35;
b4 = 28;
spalt = 0.4;

mitteY = tiefe / 2;
mitteX = breite/2;

RemMMy = 42;
RemMMx = 33;
RemMMAbstandy = 0;

F5 = 0.001;


difference()
{
	union()
	{
if (part=="assembled")
{
		Unterteil(breite);
		translate([0,0,h1+deckelLift])	Oberteil(breite);
		translate([0,(tiefe+tiefe3)/2,h1+h3+h4+h5+2*deckelLift])rotate([180,0,0])Deckel(breite);
		color("red") translate([breite/2-14/2,b1+1.5,5]) rotate([-90,0,-90])Schienenhalter();
		if (showPlatinen==true)
		{	
			translate([d-31.5+1,d-100+0.5,9])	color("White") 	rotate([0,0,90])	import("REM-C-mit_Sockel_u_Stecker.stl",convexity=5);
		}
}
else
{
	if (part=="Unterteil")
	{
		Unterteil(breite);
		if (showPlatinen==true)
		{	
			translate([d-31.5+1,d-100+0.5,9])	color("White") 	rotate([0,0,90])	import("REM-C-mit_Sockel_u_Stecker.stl",convexity=5);
		}

	}
	if (part=="Oberteil")
	{
		Oberteil(breite);
		if (showPlatinen==true)
		{	
			translate([d-31.5+1,d-100+0.5,9-h1])	color("White") 	rotate([0,0,90])	import("REM-C-mit_Sockel_u_Stecker.stl",convexity=5);
		}
	}
	if (part=="Oberteil_mit_Deckel")
	{
		color("red")translate([0,(tiefe+tiefe3)/2+F5,h3+h4+h5+deckelLift])rotate([180,0,0])Deckel(breite);
		Oberteil(breite);
		if (showPlatinen==true)
		{	
			translate([d-31.5+1,d-100+0.5,9-h1])	color("White") 	rotate([0,0,90])	import("REM-C-mit_Sockel_u_Stecker.stl",convexity=5);
		}
	}
	if (part=="Deckel")
	{
			Deckel(breite);
	}
	if (part=="Schnapper")	rotate([-90,0,0])Schienenhalter();
	if (part=="all")
	{
		Unterteil(breite);
		translate([breite+10,0,5]) Oberteil(breite);
		translate([2*breite+20,0,0])Deckel(breite);
    translate([2*breite+20,50,3])rotate([-90,0,0])Schienenhalter();
		
		if (showPlatinen==true)
		{	
			translate([d-31.5+1,d-100+0.5,9])	color("White") 	rotate([0,0,90])	import("REM-C-mit_Sockel_u_Stecker.stl",convexity=5);
			translate([d-31.5+1+breite+10,d-100+0.5,9-h1+5])	color("White") 	rotate([0,0,90])	import("REM-C-mit_Sockel_u_Stecker.stl",convexity=5);
		}
	}
}
}
	//translate([33,-25,-17])cube([100,200,100]);
}


module Deckel(breite)
{
	da = d + 0.5;
	cube([breite,tiefe3,d]);	 // Deckel
	translate([d,0,0])cube([breite-2*d,d,d+2]);	 // Seitenwand
  // rechtes
	dx = 0.1;
	translate([2*d +dx/2  ,d,0])cube([d,tiefe3-2*da,d+2]);	  // rechts
  translate([2*d +dx/2  ,tiefe3-2*da,3])rotate([90,0,0])cylinder(h=tiefe3-2*da,d=1,$fn=20); // rechts 
	// links
	translate([breite-3*d-dx/2,d,0])cube([d,tiefe3-2*da,d+2]);	
  translate([breite -2*d-dx/2 ,tiefe3-2*da,3])rotate([90,0,0])cylinder(h=tiefe3-2*da,d=1,$fn=20);

  translate([mitteX,15,1])scale(0.5)linear_extrude(height=3)text(Vers,halign="center");

}  

module Deckelschienen()
{
	dy = 32.5;
	translate([0,29+dy,32.5])
	rotate([90,0,0])
	linear_extrude(height=dy,convexity=2)
	polygon(points = [ [0,0], [2*d,0],[2*d,-3],[0,-8] ], convexity = 2);
}

module Unterteil(breite)
{
	difference()
	{
		//translate([-d-0.001,0,118])  // debugging
		cube([breite,tiefe,h1-h1debug]);																				// Aussenwand
		translate([d,d,h2+d+F5])cube([breite-2*d,tiefe-2*d,h1-d-h2]);		// Innenwand
    // Kabelzufuehrungen
		translate([61,75,7+h2+d+F5])cube([3,15.599,5]);		//  3.3V   mit einer Schicht verschlossen da optional
		translate([61+2*2.54,75,7+h2+d+F5])cube([3,15.599,5]);		// 3.3V mit einer Schicht verschlossen da optional
		for (i=[2*5.08:5.08:7*5.08])
		{
			translate([40.7-2*5.08+i,-5,7+h2+d+F5])cube([3,20,5]);		//  Spannungsanschluss
		}
		for (i=[0:5.08:1*5.08])
		{
			translate([40.7-2*5.08+i,0.401,7+h2+d+F5])cube([3,20,5]);		//  Spannungsanschluss Optional
		}
		for (i=[0:5.08:1*5.08])
		{
			translate([6.5+i,-5,7+h2+d+F5])cube([3,20,5]);		//  Spannungsanschluss
		}
		
		
		translate([35.5,75,22.5])cube([17,20,14]);		// Ausschnitt für RJ45
		translate([9.5,85,20.5])uUSB();		// Ausschnitt für USB
		
		translate([0,b1,0])Railausschnitt(breite+1);										// Schienenausschnitt
		translate([breite/2-14/2-spalt,0-F5,2-2*spalt-F5])cube([14+2*spalt,b1+2*d+F5,3+2*spalt]);		// Schnapperausschnitt
  	translate([breite/2-3.5,10,0])		cylinder(h=8,d=3.0,$fn=20);   // Loch fuer Schnapperverankerung
		wa = 3;  // Wanddicke Aussparungen
		translate([breite/2-10/2,0-F5,d-4.9+2*F5])cube([10,13,h2]);		      // Wartungsoeffnung
		translate([wa,wa,-F5])cube([(breite-14)/2-2*wa,b1-2*wa,h2]);	    // Materialsparen unten1
		translate([(breite+14)/2+wa,wa,-F5])cube([(breite-14)/2-2*wa,b1-2*wa,h2]);	    // Materialsparen unten2
		translate([wa,tiefe-b4+wa,-F5])cube([breite-2*wa,b1-2*wa,h2]);		// Materialsparen unten3
		translate([(breite-14)/2+1.5,0,1.6+d])rotate([60,0,0])translate([0,0,-3])cube([4,3,7]);		// Rampe fuer Schnappernase
		translate([(breite-14)/2+5.5-F5,-1,1.6+d])rotate([20,0,0])translate([0,0,-0])cube([4,3,7]);		// Rampe fuer Schraubendreher
		// Schnapperaussparungen
		Schnapperaussparungen(10,h1-26.5+22);
		
	}
	  // Logo und Version
    translate([mitteX,tiefe-12,h2+d-0.4])scale(0.5)RPLogo();
 	  translate([mitteX,tiefe-27,h2+d-0.8])scale(0.5)linear_extrude(height=3)text(Vers,halign="center");

	// Platinenhalterungen
	phx = (RemMMx)/2 + 6;// breite/2 - d -2.25-0.5;	// Mittenabstand Platinenhalter x
	phy = tiefe/2-d-2-8;
	phy2 = RemMMAbstandy/2+2.6;


	echo("Unterteilloecher:", 2phx=2*phx, 2phy=2*phy, 2phy2=2*phy2, dpy=phy-phy2);
	// Abstandsbolzen
	//Bolzenpositionen festlegen
	translate([mitteX+phx,mitteY+phy,0]) Platinenhalter(2,0);
	translate([mitteX-phx,mitteY+phy,0]) Platinenhalter(2,0);
	translate([mitteX+phx,mitteY-phy,0]) Platinenhalter(2,0);
	translate([mitteX-phx,mitteY-phy,0]) Platinenhalter(2,0);
	// Schraublochbolzen
	translate([6.5,25,0]) Platinenhalter(5);
	translate([66.5,58,0]) Platinenhalter(5);
	// Haltekante nach oben
	hky = 3.75;
	
	if ( generateStuetzstruktur)
	{ 
		di = 0.41;
		color("blue")
		{	// Fuer Schnapperlement
			hull()
			{
				translate([29,0,4-0.21])cube([12,13,1]);	
				translate([33,1,0])cube([8,9,1]);	
			}
		// Fuer Bodenhohlräümen	
		translate([4,9,-0.10])cube([21,di,5-0.21]);		// z -0.1 wegen bug in Cura
		translate([4,15,0])cube([21,di,5-0.21]);		
		translate([14,4,0])cube([di,17,5-0.21]);		// quer

		translate([47,9,0])cube([21,di,5-0.21]);		
		translate([47,15,0])cube([21,di,5-0.21]);		
		translate([57,4,0])cube([di,17,5-0.21]);		// quer

		translate([28,26,0])cube([16,di,5-0.21]);		
		translate([0,36,0])cube([breite,di,5-0.21]);		
		translate([0,47,0])cube([breite,di,5-0.21]);		
		translate([breite/4,27,0])cube([di,29,5-0.21]);		// quer
		translate([2*breite/4,26,0])cube([di,29,5-0.21]);		// quer
		translate([3*breite/4,27,0])cube([di,29,5-0.21]);		// quer

		translate([4,70,0])cube([breite-8,di,5-0.21]);		
		translate([4,80,0])cube([breite-8,di,5-0.21]);		
		translate([breite/4,67,0])cube([di,18,5-0.21]);		// quer
		translate([2*breite/4,67,0])cube([di,18,5-0.21]);		// quer
		translate([3*breite/4,67,0])cube([di,18,5-0.21]);		// quer
		}
	}
}


module Schnapperaussparungen(schnapperbreite,h=22)
{
		at = 2;  	// tiefe Aussparung
		ah = 2;   	// Hoehe Aussparung
		ab = schnapperbreite;  		// Breite Aussparung
		//h = 22;	// Position Z
	  yd = 10;
	  y1 =  mitteY - yd;
    y2 =  mitteY + yd;

		translate([       0,y1  , h]) rotate([0,0,-90]) Schnapperaussparung(ab,at,ah);
		translate([  breite,y1, h]) rotate([0,0, 90]) Schnapperaussparung(ab,at,ah);
		translate([       0,y2  , h]) rotate([0,0,-90]) Schnapperaussparung(ab,at,ah);
		translate([  breite,y2, h]) rotate([0,0, 90]) Schnapperaussparung(ab,at,ah);
}

module Schnapperaussparung(ab,at,ah)
{
	translate([-ab/2,-F5,0])cube([ab,at,ah]);
	translate([-ab/2,1,1])cube([ab,at,5]);
}
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

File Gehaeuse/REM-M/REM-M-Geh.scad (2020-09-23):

//
//	Gerause für REM-M  / Din rail
//
//  by Rainer Petzoldt
//
//  Slicen ohne Stützstruktur ;  4 Wandlinien ;  3 Obere- und untere Schichten
//     generateStuetzstruktur = true setzen
//

/* width in TE (=18mm) */
AnzTE = 2;   // [1:0.5:12]
/* show all parts assembled */
part = "Oberteil" ; // [Unterteil, Oberteil, Deckel, Klammer, Oberteil_mit_Deckel, Schnapper, all, assembled]
showPlatinen = false;
generateStuetzstruktur = true;
useVerschraubung = true;
useSchnapper = false;

// *******************************************************************

/* [Hidden] */
deckelLift = 1*15;   // zieht module auseinander (Explosionszeichnung)
h1debug =  0*19;   // 0 = no debug  erniedrigt aussenwand um h1debug mm
Vers =  "V2.0.1";
TE = 18;	// Teilungseinheit
d = 1.5;   				// Wanddicke

breite = AnzTE * TE-0.5+1;  // Gesamtbreite aussen
tiefe = 91;				// Tiefe unterste Ebene
tiefe2 = 62-12;			// Tiefe mittlere Ebene
tiefe3 = 45-10;			// Tiefe mittlere Ebene

h1 = 26.5;				// Hoehe Unterteil gesamt aussen
h2 = 5;           // Aussparung fuer Schiene 
h3 = 5;         // Hoehe unterste Deckelschicht
h4 = 17;          // Hoehe mittlere Deckelschicht
h5 = 22-10;          // Hoehe obere Deckelschicht
b1 = 28-2.5;
b2 = 0.5;
b3 = 35;
b4 = 28;
spalt = 0.4;

mitteY = tiefe / 2;
mitteX = breite/2;

RemMMy = 42;
RemMMx = 33;
RemMMAbstandy = 0;


F5 = 0.001;


difference()
{
	union()
	{
	if (part=="assembled")
	{
			Unterteil(breite);
			translate([0,0,h1+deckelLift])	Oberteil(breite);
			translate([0,(tiefe+tiefe3)/2,h1+h3+h4+h5+2*deckelLift])rotate([180,0,0])Deckel(breite);
			color("red") translate([breite/2-14/2,b1+1.5,5]) rotate([-90,0,-90])Schienenhalter();
		  color("orange") translate([mitteX,mitteY,23.3-3+deckelLift]) Klammer(breite);

			if (showPlatinen==true)
			{	
				dy=2;
				translate([mitteX-RemMMx/2,mitteY-RemMMy-RemMMAbstandy/2,9]) color("Green") import("REM-MM-mit_Stecker.stl",convexity=5);
				translate([mitteX+RemMMx/2,mitteY+RemMMy+RemMMAbstandy/2,9]) color("Red") rotate([0,0,180])import("REM-MM-mit_Stecker.stl",convexity=5);
				translate([33+1.5+0.25,63,45+deckelLift]) color("Blue") rotate([0,180,0])import("REM-MH-mit_Stecker.stl",convexity=5);
				//translate([-105,2-100,9]) color("White") rotate([0,0,90])import("REM-C-mit_Sockel_u_Stecker.stl",convexity=5);
			}
	}

	if (part=="Unterteil")
	{
		Unterteil(breite);
		if (showPlatinen==true)
		{	
			translate([mitteX-RemMMx/2,mitteY-RemMMy-RemMMAbstandy/2,9]) color("Green") import("REM-MM-mit_Stecker.stl",convexity=5);
			translate([mitteX+RemMMx/2,mitteY+RemMMy+RemMMAbstandy/2,9]) color("Red") rotate([0,0,180])import("REM-MM-mit_Stecker.stl",convexity=5);
		}
	}
	if (part=="Oberteil")
	{
		//rotate([0,-90,0])	
		{
			if (useSchnapper)
			{
				Oberteil(breite);
			}
			else
			{
				difference()
				{
					Oberteil(breite);
					translate([-1,-1,-100])cube([100,100,100]);
				}
			}
			if (showPlatinen==true)
			{	
				translate([33+1.5+0.25,63,18.5]) color("Blue") rotate([0,180,0])import("REM-MH-mit_Stecker.stl",convexity=5);
			}
		}
	}

	if (part=="Klammer")
	{
		if (showPlatinen==true)
		{	
		  translate([mitteX,mitteY,23.3-3]) Klammer(breite);
			translate([mitteX-RemMMx/2,mitteY-RemMMy-RemMMAbstandy/2,9]) color("Green") import("REM-MM-mit_Stecker.stl",convexity=5);
			translate([mitteX+RemMMx/2,mitteY+RemMMy+RemMMAbstandy/2,9]) color("Red") rotate([0,0,180])import("REM-MM-mit_Stecker.stl",convexity=5);
			translate([33+1.5+0.25,63,45+deckelLift]) color("Blue") rotate([0,180,0])import("REM-MH-mit_Stecker.stl",convexity=5);
		}
		else
		{ 
		  Klammer(breite);
		}

	}

	if (part=="Oberteil_mit_Deckel")
	{
		//rotate([0,-90,0])	
		{
			Oberteil(breite);
			color("red")translate([0,(tiefe+tiefe3)/2,h3+h4+h5+deckelLift])rotate([180,0,0])Deckel(breite);

		//translate([breite+10,0,0])		Deckel(breite);  // nur test

			if (showPlatinen==true)
			{	
				translate([33+1.5+0.25,63,18.5]) color("Blue") rotate([0,180,0])import("REM-MH-mit_Stecker.stl",convexity=5);
			}
		}
	}	if (part=="Deckel")
	{
			Deckel(breite);
	}
	if (part=="Schnapper")	rotate([-90,0,0])Schienenhalter();
	if (part=="all")
	{
		abst = 10;
		Unterteil(breite);
		translate([breite+abst,0,0])	Oberteil(breite);
		translate([2*breite+2*abst,40,3]) rotate([-90,0,0])Schienenhalter();
		translate([2*breite+2*abst,0,0])Deckel(breite);
		if (showPlatinen==true)
		{	
			translate([1.5+0.25,2,9]) color("Green") import("REM-MM-mit_Stecker.stl",convexity=5);
			translate([33+1.5,90-1,9]) color("Red") rotate([0,0,180])import("REM-MM-mit_Stecker.stl",convexity=5);
			rotate([0,-90,0])	translate([33+1.5+0.25,63,18.5-(breite+h3+h4+h5+10)]) color("Blue") rotate([0,180,0])import("REM-MH-mit_Stecker.stl",convexity=5);
      translate([-105,2-100,9]) color("White") rotate([0,0,90])import("REM-C-mit_Sockel_u_Stecker.stl",convexity=5);
		}
	}

}
	//translate([33,-25,7])cube([100,200,100]);
}


module Klammer(breite)
{
	kb = 30;
	kt = 18.5;
	lb = 18;
	lt = 6.5;
	difference()
	{
		translate([0,0,3])cube([kb,kt,6],center=true);
		translate([ 3.73, 4.25,-1])   cube([lb,lt,8],center=true);
		translate([-3.73,-4.25,-1])cube([lb,lt,8],center=true);
	}
	ho = 21;
	h1 = 15;
	h2 = 12;
	translate([0,0,ho-h1/2])cube([3,15,h1],center=true);
	translate([0,0,ho-h2/2])cube([15,3,h2],center=true);
	translate([0,0,ho-h2/2-3])cube([30,3,h2],center=true);
}

module Deckel(breite)
{
	da = d + 0.5;
	cube([breite,tiefe3,d]);	 // Deckel
	translate([d,0,0])cube([breite-2*d,d,d+2]);	 // Seitenwand
	translate([2*d         ,d,0])cube([d,tiefe3-2*da,d+2]);	
	translate([breite-3*d,d,0])cube([d,tiefe3-2*da,d+2]);	
  translate([2*d         ,tiefe3-2*da,3])rotate([90,0,0])cylinder(h=tiefe3-2*da,d=1,$fn=20);
  translate([breite -2*d ,tiefe3-2*da,3])rotate([90,0,0])cylinder(h=tiefe3-2*da,d=1,$fn=20);
}  

module Deckelschienen()
{
	dy = 32.5;
	translate([0,29+dy,32.5])
	rotate([90,0,0])
	linear_extrude(height=dy,convexity=2)
	polygon(points = [ [0,0], [2*d,0],[2*d,-3],[0,-8] ], convexity = 2);
}


module Unterteil(breite)
{
	difference()
	{
		//translate([-d-0.001,0,8])  // debugging
		cube([breite,tiefe,h1-h1debug]);																				// Aussenwand
		translate([d,d,h2+d+F5])cube([breite-2*d,tiefe-2*d,h1-d-h2]);		// Innenwand
		translate([d,-d,5+h2+d+F5])cube([breite-2*d,tiefe+2*d,h1-d-h2]);		// Seitenwände weg für Kabel
		translate([0,b1,0])Railausschnitt(breite+1);										// Schienenausschnitt
		translate([breite/2-14/2-spalt,0-F5,2-2*spalt-F5])cube([14+2*spalt,b1+2*d+F5,3+2*spalt]);		// Schnapperausschnitt
  	translate([breite/2-3.5,10,0])		cylinder(h=8,d=3.0,$fn=20);   // Loch fuer Schnapperverankerung
		wa = 3;  // Wanddicke Aussparungen
		translate([breite/2-10/2,0-F5,d-4.9+2*F5])cube([10,13,h2]);		      // Wartungsoeffnung
		translate([wa,wa,-F5])cube([(breite-14)/2-2*wa,b1-2*wa,h2]);	    // Materialsparen unten1
		translate([(breite+14)/2+wa,wa,-F5])cube([(breite-14)/2-2*wa,b1-2*wa,h2]);	    // Materialsparen unten2
		translate([wa,tiefe-b4+wa,-F5])cube([breite-2*wa,b1-2*wa,h2]);		// Materialsparen unten3
		translate([(breite-14)/2+1.5,0,1.6+d])rotate([60,0,0])translate([0,0,-3])cube([4,3,7]);		// Rampe fuer Schnappernase
		translate([(breite-14)/2+5.5-F5,-1,1.6+d])rotate([20,0,0])translate([0,0,-0])cube([4,3,7]);		// Rampe fuer Schraubendreher
		// Schnapperaussparungen
		if (useSchnapper) Schnapperaussparungen(10);
		
	}
	  // Logo und Version
    translate([mitteX,tiefe-12,h2+d-0.4])scale(0.5)RPLogo();
 	  translate([mitteX,tiefe-27,h2+d-0.8])scale(0.5)linear_extrude(height=3)text(Vers,halign="center");

	// Platinenhalterungen
	phx2 = (RemMMx)/2 - 2.5;// breite/2 - d -2.25-0.5;	// Mittenabstand Platinenhalter x
	phx = (RemMMx)/2 - 7.5;// breite/2 - d -2.25-0.5;	// Mittenabstand Platinenhalter x
	phy = tiefe/2-d-2-3;
	phy2 = RemMMAbstandy/2+2.6;
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

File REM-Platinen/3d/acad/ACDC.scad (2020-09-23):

cube([23.5,15.1,1.6]);
translate([1,-3,0])cube([2,3,1.6]);
translate([4,-3,0])cube([2,3,1.6]);
translate([20.5 - 4,-3,0])cube([3,4,1.6]);
translate([20.5,-3,0])cube([3,4,1.6]);

translate([3,5,0])cylinder(h=10,d=5,$fn=20);
translate([20,11,5])rotate([90,0,0])cylinder(h=10,d=7,$fn=20);
translate([6,2,0])cube([10,10,9]);

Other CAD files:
REM-Platinen/3d/LED_3mm_long.FCStd
REM-Platinen/Platinen/modules/3dpackages/ZMPT107.step
Gehaeuse/REM-M/REM-M-Unterteil_V2.0.stl
Gehaeuse/REM-M/REM-M-Klammer_V1.2.stl
REM-Platinen/3d/Lolin32.FCStd
REM-Platinen/3d/acad/ACDC.FCStd
REM-Platinen/Platinen/modules/3dpackages/LED_D3.0mm_long.step
REM-Platinen/Platinen/modules/3dpackages/MicroButton2.step
REM-Platinen/Platinen/modules/3dpackages/PinHeader_2x05_P2.54mm_Vertical_mit_Stecker.step
REM-Platinen/Platinen/modules/3dpackages/USR-ES1.step
REM-Platinen/Platinen/modules/3dpackages/pxc_1726189_05_MKKDSN-1-5-6-5-08_3D.stp

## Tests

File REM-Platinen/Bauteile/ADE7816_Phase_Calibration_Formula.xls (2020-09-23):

ADE7816 Phase Calibration Calculator
To use the calculator enter to frequency of your input signal and the desired phase shift in degrees (highlighted in yellow)
Fs (Sampling frequency) | 8000 | (Hz)
Fundamental frequency | 50 | (Hz)
Desired degree | 0 | (degree) | Calibration Range: -6.75deg ~ +6.75deg
Status | VALID
w=2*pi*f0/Fs | 0.03926990817
β (fraction number) | 0.5003857793
Value to write to PCF_x_COEFF | #NAME?
ADE7816 Phase Calibration Formula Details
The formula to compute β:
if β_fract >= 0:
β = 223 * β_fract
if β_fract < 0:
β = 228 + 223 * β_fract
φ is the desired the compensation (current versus voltage, usually a negative value).
w=2*pi*F0/Fs, where f0 is fundamental frequency, Fs=8000Hz (sampling frequency).
φ and w should be both in degrees or both in radians.

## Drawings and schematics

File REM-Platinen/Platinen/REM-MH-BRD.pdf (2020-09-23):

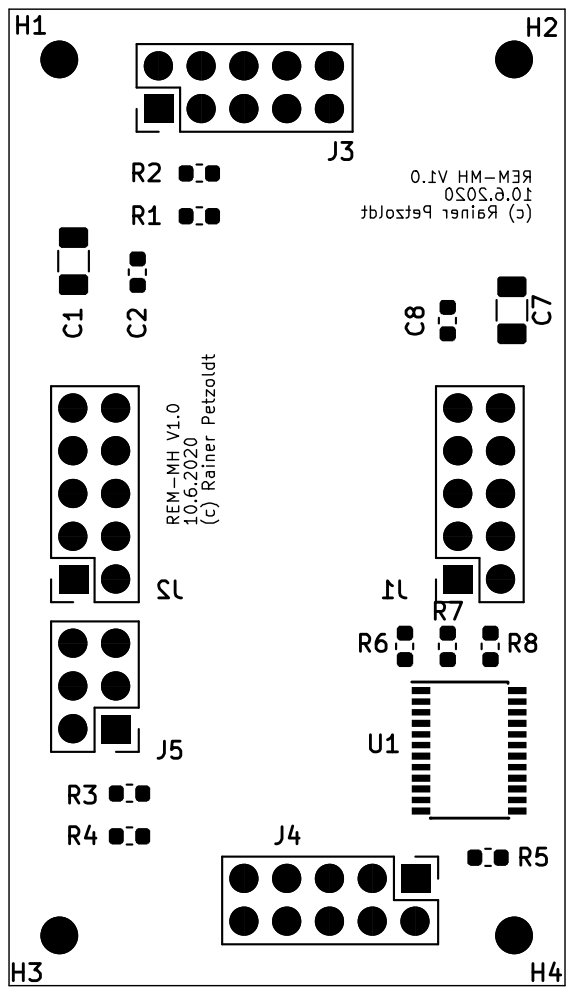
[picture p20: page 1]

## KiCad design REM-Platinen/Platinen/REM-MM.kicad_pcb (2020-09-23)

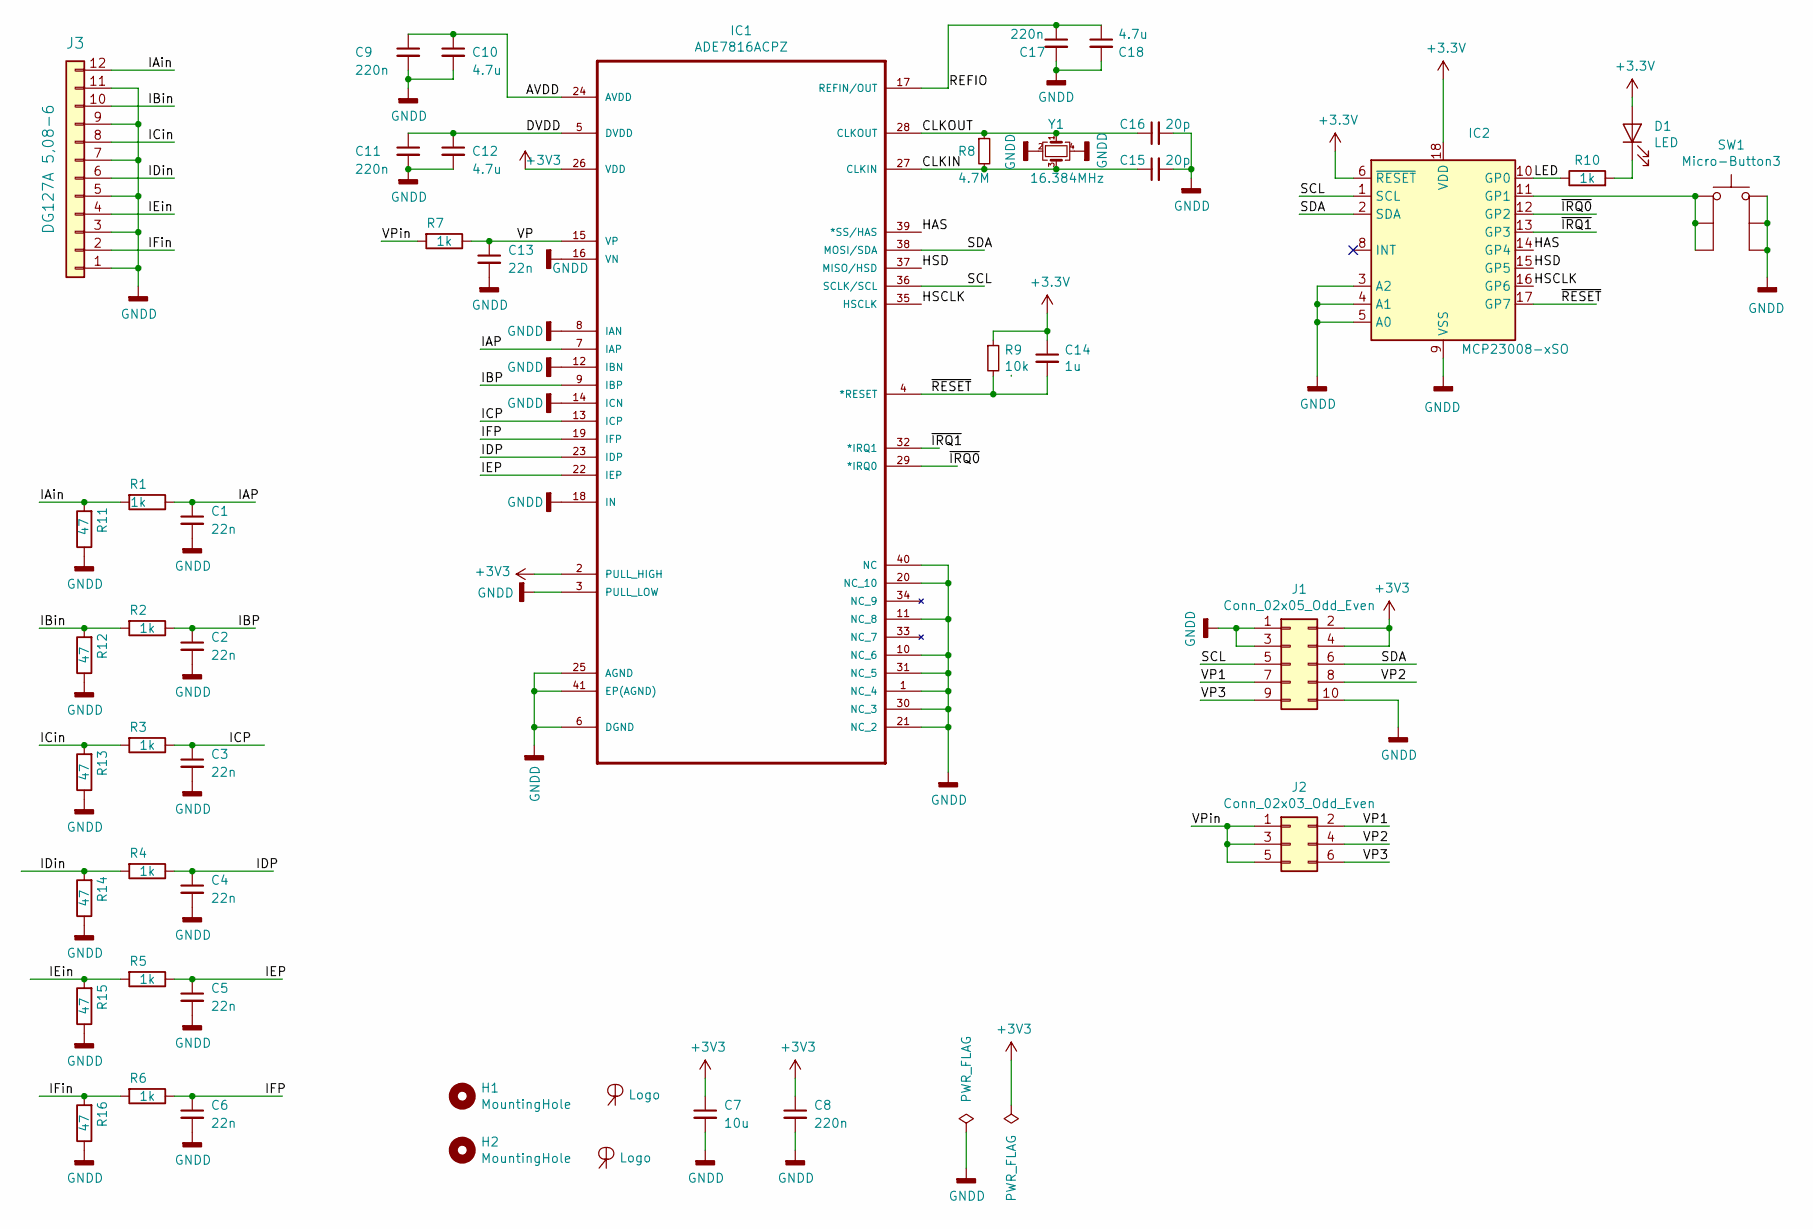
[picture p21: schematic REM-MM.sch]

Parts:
C1, C2, C3, C4, C5, C6, C13: 22n; C_0603_1608Metric
C7: 10u; C_1206_3216Metric
C8, C9, C11, C17: 220n; C_0603_1608Metric
C10, C12, C18: 4.7u; C_1206_3216Metric
C14: 1u; C_0603_1608Metric
C15, C16: 20p; C_0603_1608Metric
D1: LED; LED_D3.0mm_long
H1, H2: MountingHole; MountingHole_2.2mm_M2
IC1: ADE7816ACPZ; QFN50P600X600X80-41N
IC2: MCP23008-xSO; SOIC-18W_7.5x11.6mm_P1.27mm
J1: Conn_02x05_Odd_Even; PinHeader_2x05_P2.54mm_Vertical_mit_Stecker
J2: Conn_02x03_Odd_Even; PinHeader_2x03_P2.54mm_Vertical
J3: DG127A 5,08-6; pxc_1726189_05_MKKDSN-1-5-6-5-08
L1, L2: Logo; LogoRP_6mm
R1, R2, R3, R4, R5, R6, R7, R10: 1k; R_0603_1608Metric
R8: 4.7M; R_0603_1608Metric
R9: 10k; R_0603_1608Metric
R11, R12, R13, R14, R15, R16: 47; R_0603_1608Metric
SW1: Micro-Button3
Y1: 16.384MHz; Crystal_SMD_2520-4Pin_2.5x2.0mm

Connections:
/AVDD: C9.1, C10.1, IC1.24 (AVDD)
/CLKIN: C15.1, IC1.27 (CLKIN), R8.2, Y1.3
/CLKOUT: C16.1, IC1.28 (CLKOUT), R8.1, Y1.1
/DVDD: C11.1, C12.1, IC1.5 (DVDD)
/HAS: IC1.39 (*SS/HAS), IC2.14 (GP4)
/HSCLK: IC1.35 (HSCLK), IC2.16 (GP6)
/HSD: IC1.37 (MISO/HSD), IC2.15 (GP5)
/IAP: C1.1, IC1.7 (IAP), R1.1
/IAin: J3.12, R1.2, R11.2
/IBP: C2.1, IC1.9 (IBP), R2.1
/IBin: J3.10, R2.2, R12.2
/ICP: C3.1, IC1.13 (ICP), R3.1
/ICin: J3.8, R3.2, R13.2
/IDP: C4.1, IC1.23 (IDP), R4.1
/IDin: J3.6, R4.2, R14.2
/IEP: C5.1, IC1.22 (IEP), R5.1
/IEin: J3.4, R5.2, R15.2
/IFP: C6.1, IC1.19 (IFP), R6.1
/IFin: J3.2, R6.2, R16.2
/LED: IC2.10 (GP0), R10.1
/REFIO: C17.1, C18.1, IC1.17 (REFIN/OUT)
/SCL: IC1.36 (SCLK/SCL), IC2.1 (SCL), J1.5
/SDA: IC1.38 (MOSI/SDA), IC2.2 (SDA), J1.6
/VP: C13.1, IC1.15 (VP), R7.1
/VP1: J1.7, J2.2
/VP2: J1.8, J2.4
/VP3: J1.9, J2.6
/VPin: J2.1, J2.3, J2.5, R7.2
/~IRQ0: IC1.29 (*IRQ0), IC2.12 (GP2)
/~IRQ1: IC1.32 (*IRQ1), IC2.13 (GP3)
/~RESET: C14.2, IC1.4 (*RESET), IC2.17 (GP7), R9.2
GNDD: C1.2, C2.2, C3.2, C4.2, C5.2, C6.2, C7.2, C8.2, C9.2, C10.2, C11.2, C12.2, C13.2, C15.2, C16.2, C17.2, C18.2, IC1.1 (NC_4), IC1.3 (PULL_LOW), IC1.6 (DGND), IC1.8 (IAN), IC1.10 (NC_6), IC1.11 (NC_8), IC1.12 (IBN), IC1.14 (ICN), IC1.16 (VN), IC1.18 (IN), IC1.20 (NC_10), IC1.21 (NC_2), IC1.25 (AGND), IC1.30 (NC_3), IC1.31 (NC_5), IC1.40 (NC), IC1.41 (EP(AGND)), IC2.3 (A2), IC2.4 (A1), IC2.5 (A0), IC2.9 (VSS), J1.1, J1.3, J1.10, J3.1, J3.3, J3.5, J3.7, J3.9, J3.11, R11.1, R12.1, R13.1, R14.1, R15.1, R16.1, SW1.2, SW1.4, SW1.6, Y1.2, Y1.4
unnamed: D1.1 (K), R10.2
unnamed: IC2.11 (GP1), SW1.1, SW1.3, SW1.5

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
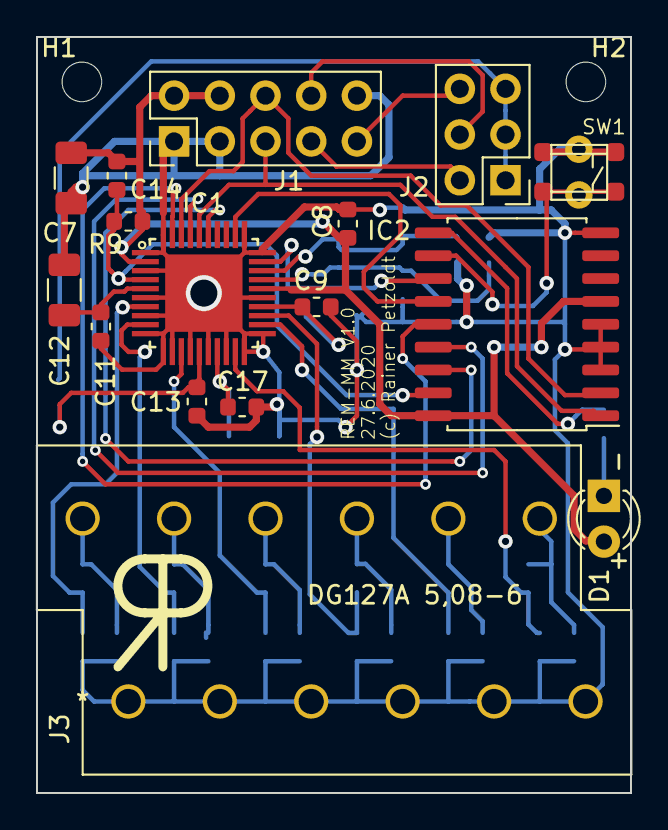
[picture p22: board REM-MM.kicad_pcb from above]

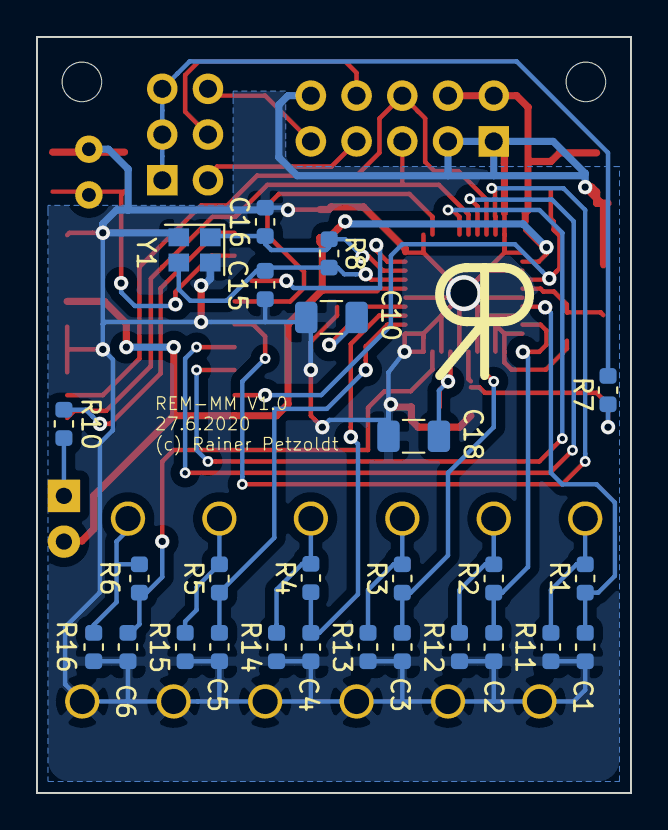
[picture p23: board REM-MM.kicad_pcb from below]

Board: 2 copper layers, 33.0 x 42.0 mm, 46 parts (27 on the bottom side), 35 nets.

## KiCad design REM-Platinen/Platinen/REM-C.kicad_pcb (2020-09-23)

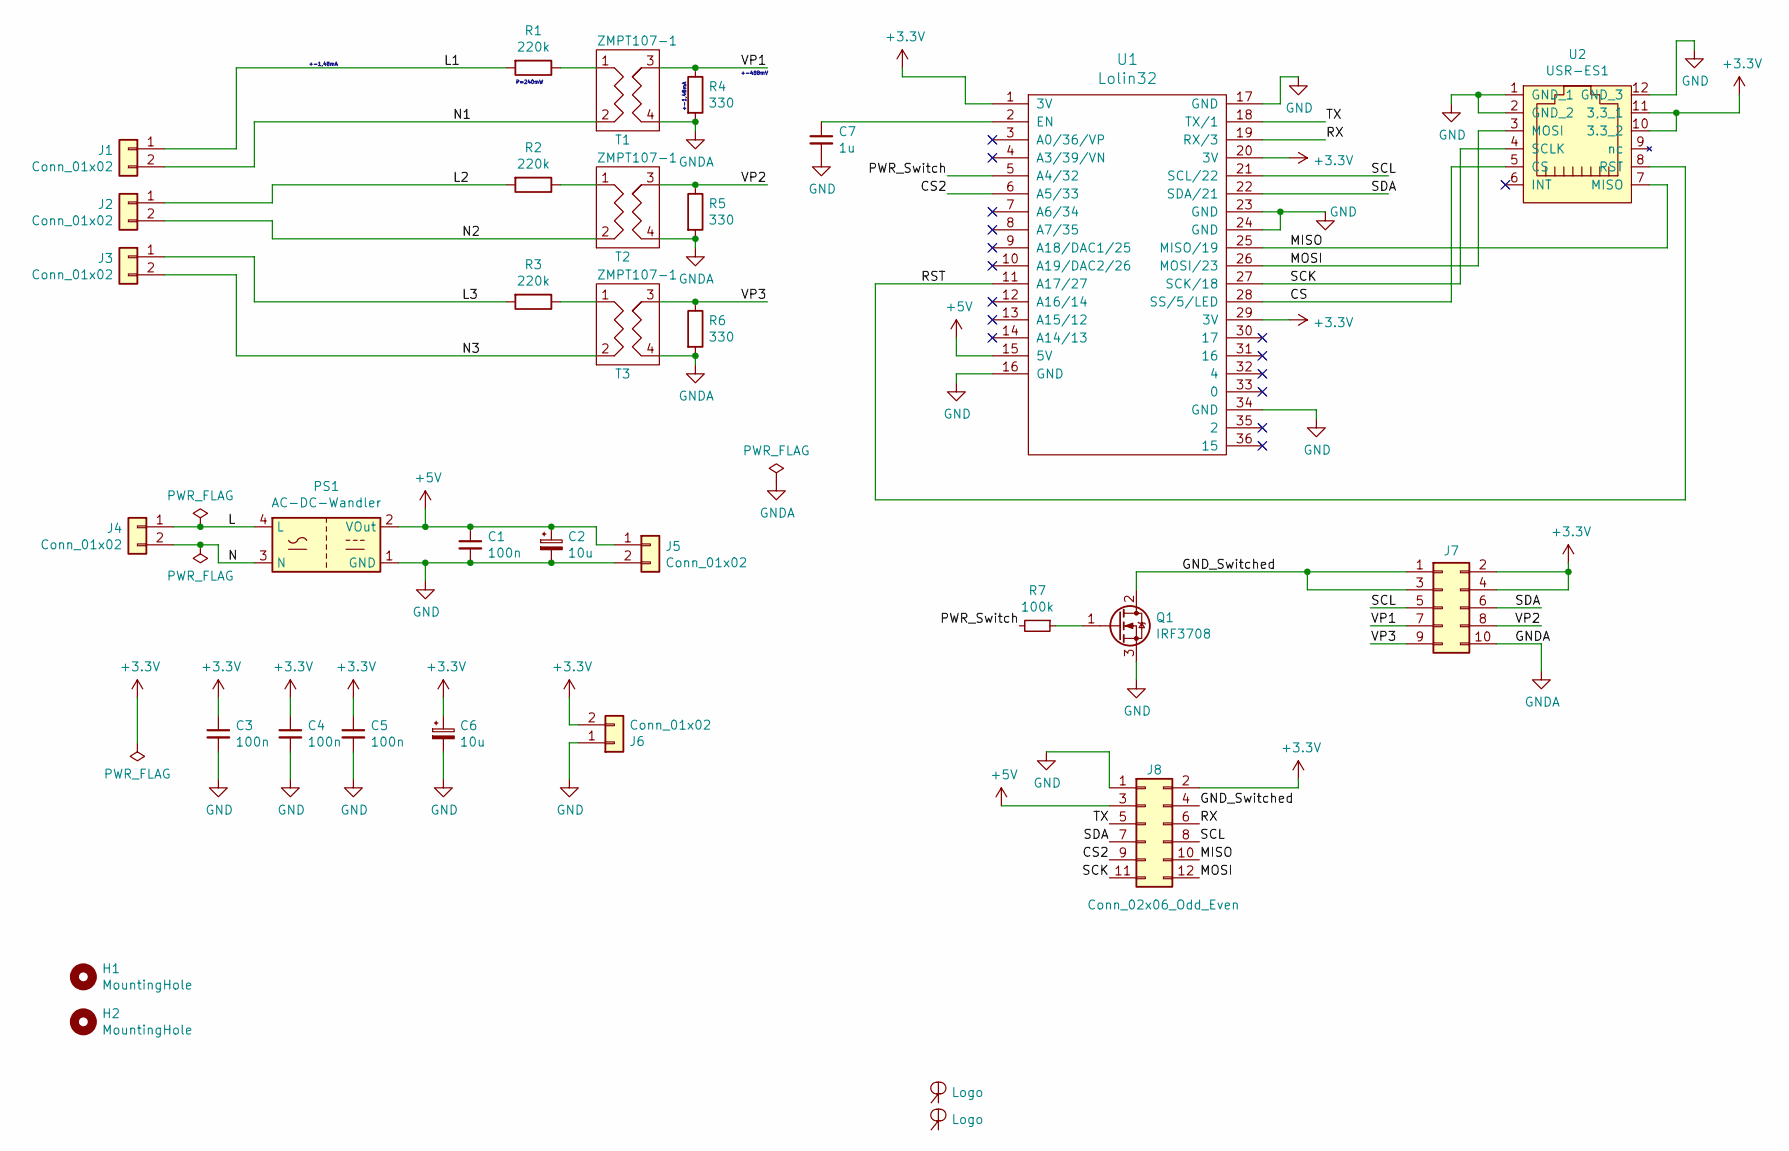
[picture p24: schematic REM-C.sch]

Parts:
C1, C3, C4, C5: 100n; C_0603_1608Metric
C2, C6: 10u; CP_Radial_D5.0mm_P2.00mm
C7: 1u; C_0805_2012Metric
H1, H2: MountingHole; MountingHole_2.2mm_M2
J1, J2, J3, J4, J5, J6: Conn_01x02; W237-102
J7: Conn_02x05_Odd_Even; PinHeader_2x05_P2.54mm_Vertical_mit_Stecker
J8: Conn_02x06_Odd_Even; PinHeader_2x06_P2.54mm_Vertical
L1, L2: Logo; LogoRP_6mm
PS1: AC-DC-Wandler; AC-DC_Wandler
Q1: IRF3708; TO-220-3_Vertical
R1, R2, R3: 220k; R_Axial_DIN0414_L11.9mm_D4.5mm_P15.24mm_Horizontal
R4, R5, R6: 330; R_Axial_DIN0207_L6.3mm_D2.5mm_P10.16mm_Horizontal
R7: 100k; R_0603_1608Metric
T1, T2, T3: ZMPT107-1; ZMPT107
U1: Lolin32; Lolin32_gesockelt
U2: USR-ES1; USR-ES1_gesockelt

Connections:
+3V3: C3.1, C4.1, C5.1, C6.1, J6.2, J7.2, J7.4, J8.2, U1.1 (3V), U1.20 (3V), U1.29 (3V), U2.10 (3.3_2), U2.11 (3,3_1)
+5V: C1.1, C2.1, J5.1, J8.3, PS1.2 (VOut), U1.15 (5V)
/CS: U1.28 (SS/5/LED), U2.5 (CS)
/CS2: J8.9, U1.6 (A5/33)
/GND_Switched: J7.1, J7.3, J8.4, Q1.2 (D)
/L: J4.1, PS1.4 (L)
/L1: J1.1, R1.2
/L2: J2.1, R2.2
/L3: J3.1, R3.2
/MISO: J8.10, U1.25 (MISO/19), U2.7 (MISO)
/MOSI: J8.12, U1.26 (MOSI/23), U2.3 (MOSI)
/N: J4.2, PS1.3 (N)
/N1: J1.2, T1.2
/N2: J2.2, T2.2
/N3: J3.2, T3.2
/PWR_Switch: R7.2, U1.5 (A4/32)
/RST: U1.11 (A17/27), U2.8 (RST)
/RX: J8.6, U1.19 (RX/3)
/SCK: J8.11, U1.27 (SCK/18), U2.4 (SCLK)
/SCL: J7.5, J8.8, U1.21 (SCL/22)
/SDA: J7.6, J8.7, U1.22 (SDA/21)
/TX: J8.5, U1.18 (TX/1)
/VP1: J7.7, R4.1, T1.3
/VP2: J7.8, R5.1, T2.3
/VP3: J7.9, R6.1, T3.3
GND: C1.2, C2.2, C3.2, C4.2, C5.2, C6.2, C7.2, J5.2, J6.1, J8.1, PS1.1 (GND), Q1.3 (S), U1.16 (GND), U1.17 (GND), U1.23 (GND), U1.24 (GND), U1.34 (GND), U2.1 (GND_1), U2.2 (GND_2~), U2.12 (GND_3)
GNDA: J7.10, R4.2, R5.2, R6.2, T1.4, T2.4, T3.4
unnamed: C7.1, U1.2 (EN)
unnamed: Q1.1 (G), R7.1
unnamed: R1.1, T1.1
unnamed: R2.1, T2.1
unnamed: R3.1, T3.1

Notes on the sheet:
+-1,48mA
P=240mW
+-488mV

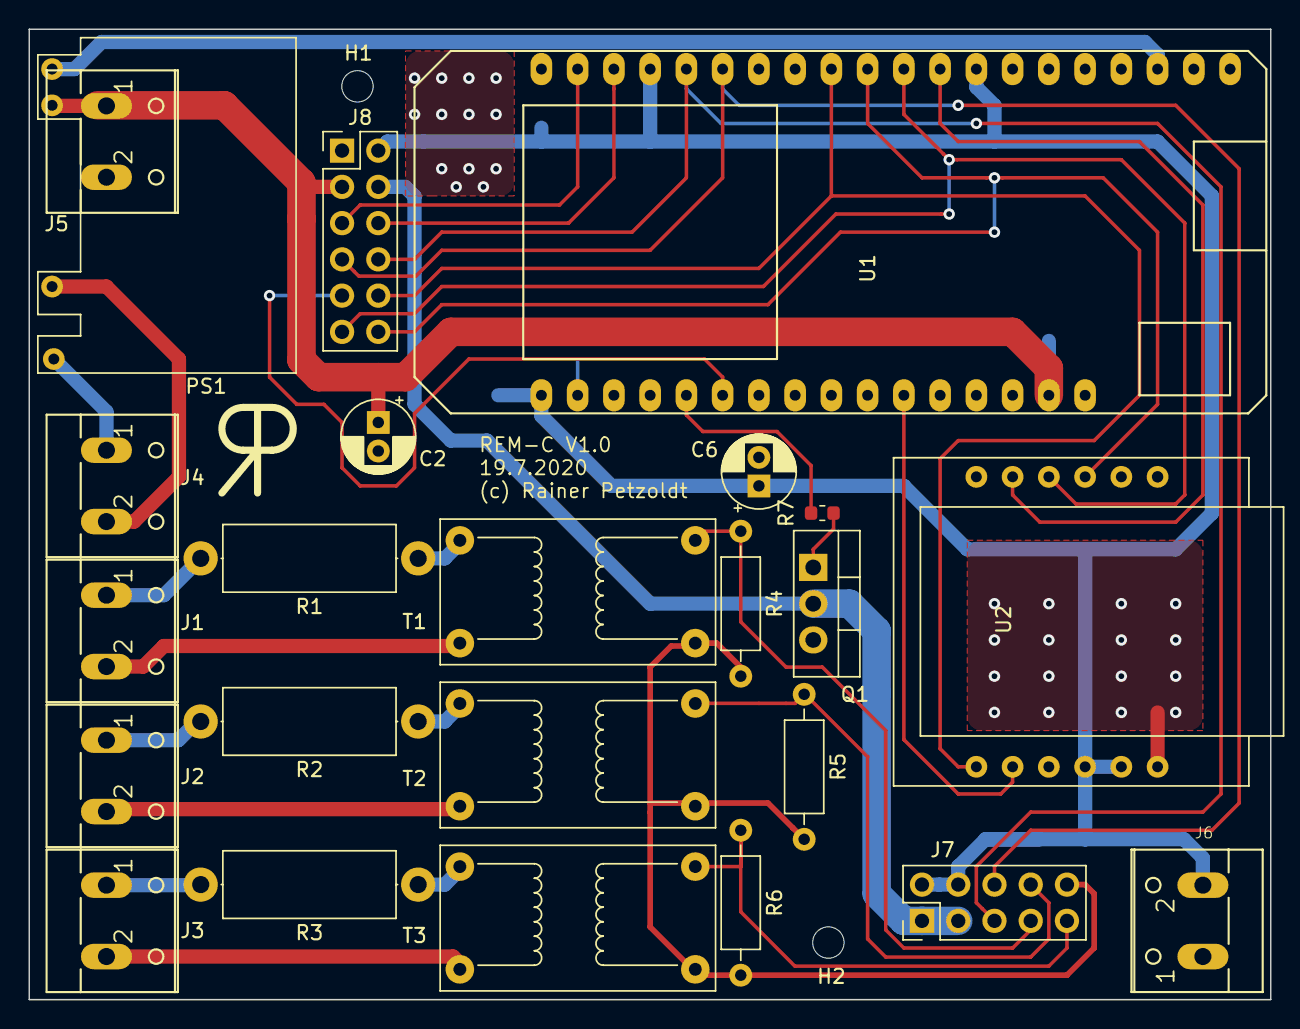
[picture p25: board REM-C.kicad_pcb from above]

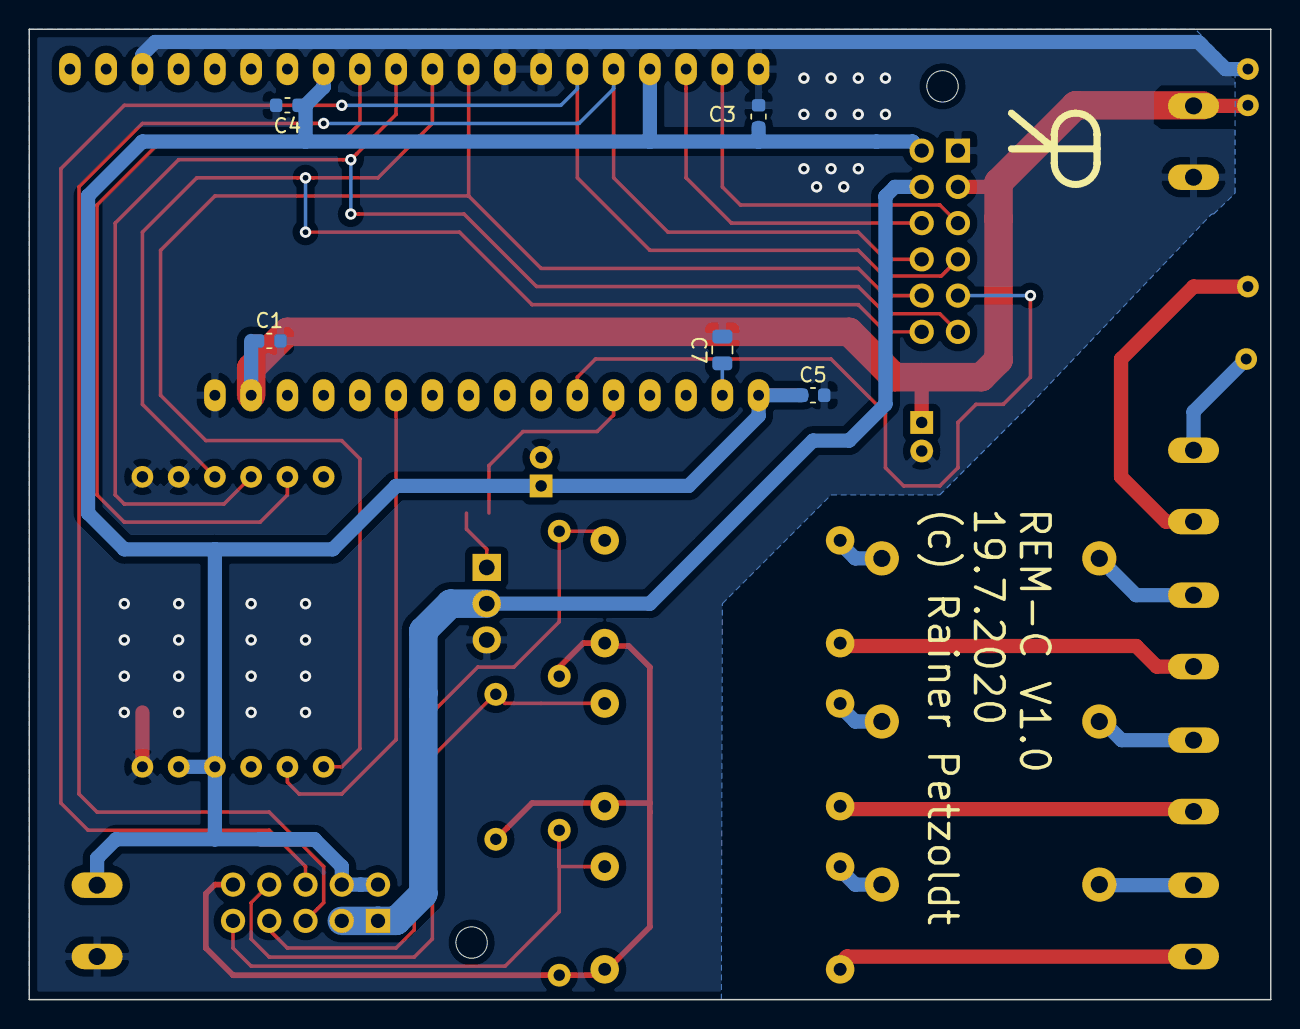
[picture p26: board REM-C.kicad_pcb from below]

Board: 2 copper layers, 87.0 x 68.0 mm, 33 parts (6 on the bottom side), 32 nets.

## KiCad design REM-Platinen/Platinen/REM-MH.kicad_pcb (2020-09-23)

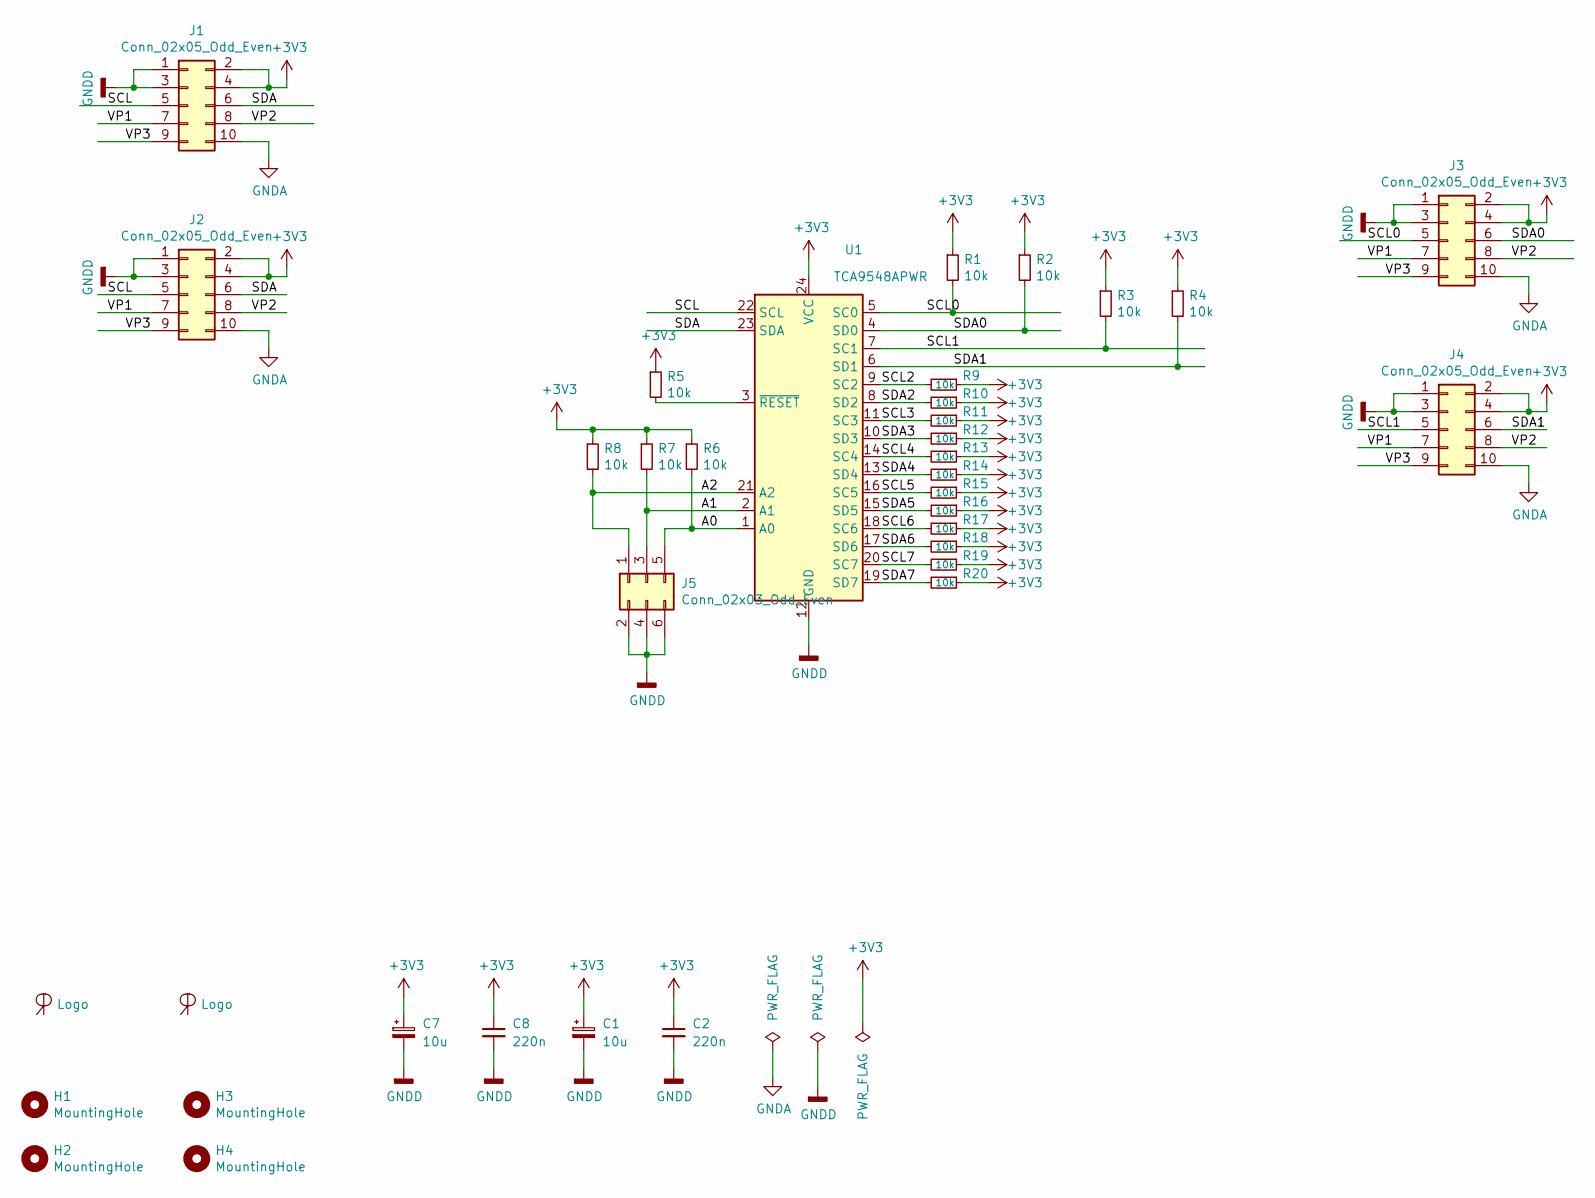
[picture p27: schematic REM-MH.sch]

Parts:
C1, C7: 10u; C_1206_3216Metric
C2, C8: 220n; C_0603_1608Metric
H1, H2, H3, H4: MountingHole; MountingHole_2.2mm_M2
J1, J2, J3, J4: Conn_02x05_Odd_Even; PinHeader_2x05_P2.54mm_Vertical_mit_Stecker
J5: Conn_02x03_Odd_Even; PinHeader_2x03_P2.54mm_Vertical
L1, L2: Logo; LogoRP_6mm
R1, R2, R3, R4, R5, R6, R7, R8, R9, R10, R11, R12, R13, R14, R15, R16, R17, R18, R19, R20: 10k; R_0603_1608Metric
U1: TCA9548APWR; TSSOP-24_4.4x7.8mm_P0.65mm

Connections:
+3V3: C1.1, C2.1, C7.1, C8.1, J1.2, J1.4, J2.2, J2.4, J3.2, J3.4, J4.2, J4.4, R1.1, R2.1, R3.1, R4.1, R5.1, R6.1, R7.1, R8.1, R9.1, R10.1, R11.1, R12.1, R13.1, R14.1, R15.1, R16.1, R17.1, R18.1, R19.1, R20.1, U1.24 (VCC)
/A0: J5.5, R6.2, U1.1 (A0)
/A1: J5.3, R7.2, U1.2 (A1)
/A2: J5.1, R8.2, U1.21 (A2)
/SCL: J1.5, J2.5, U1.22 (SCL)
/SCL0: J3.5, R1.2, U1.5 (SC0)
/SCL1: J4.5, R3.2, U1.7 (SC1)
/SCL2: R9.2, U1.9 (SC2)
/SCL3: R11.2, U1.11 (SC3)
/SCL4: R13.2, U1.14 (SC4)
/SCL5: R15.2, U1.16 (SC5)
/SCL6: R17.2, U1.18 (SC6)
/SCL7: R19.2, U1.20 (SC7)
/SDA: J1.6, J2.6, U1.23 (SDA)
/SDA0: J3.6, R2.2, U1.4 (SD0)
/SDA1: J4.6, R4.2, U1.6 (SD1)
/SDA2: R10.2, U1.8 (SD2)
/SDA3: R12.2, U1.10 (SD3)
/SDA4: R14.2, U1.13 (SD4)
/SDA5: R16.2, U1.15 (SD5)
/SDA6: R18.2, U1.17 (SD6)
/SDA7: R20.2, U1.19 (SD7)
/VP1: J1.7, J2.7, J3.7, J4.7
/VP2: J1.8, J2.8, J3.8, J4.8
/VP3: J1.9, J2.9, J3.9, J4.9
GNDA: J1.10, J2.10, J3.10, J4.10
GNDD: C1.2, C2.2, C7.2, C8.2, J1.1, J1.3, J2.1, J2.3, J3.1, J3.3, J4.1, J4.3, J5.2, J5.4, J5.6, U1.12 (GND)
unnamed: R5.2, U1.3 (~RESET)

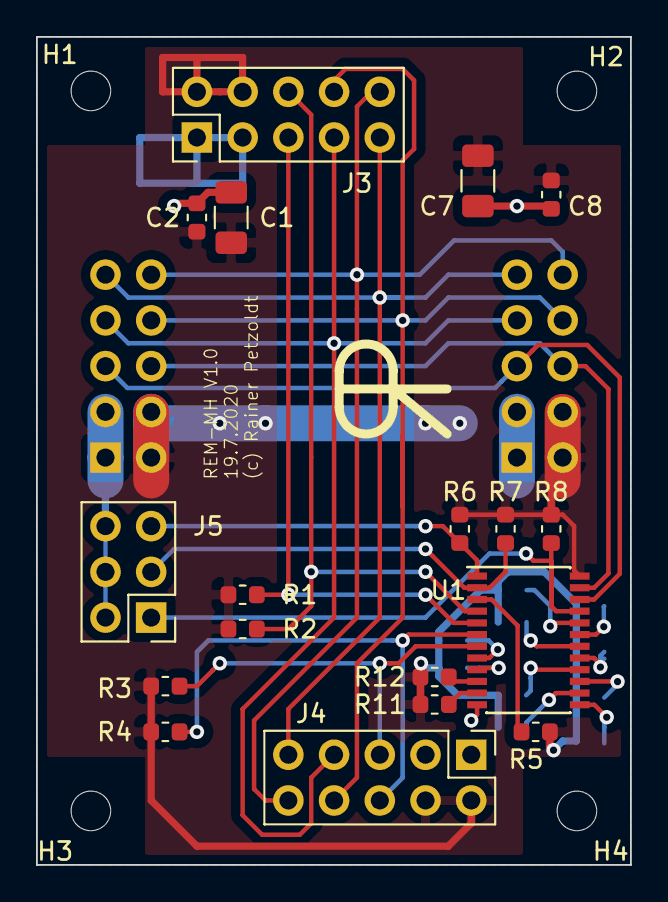
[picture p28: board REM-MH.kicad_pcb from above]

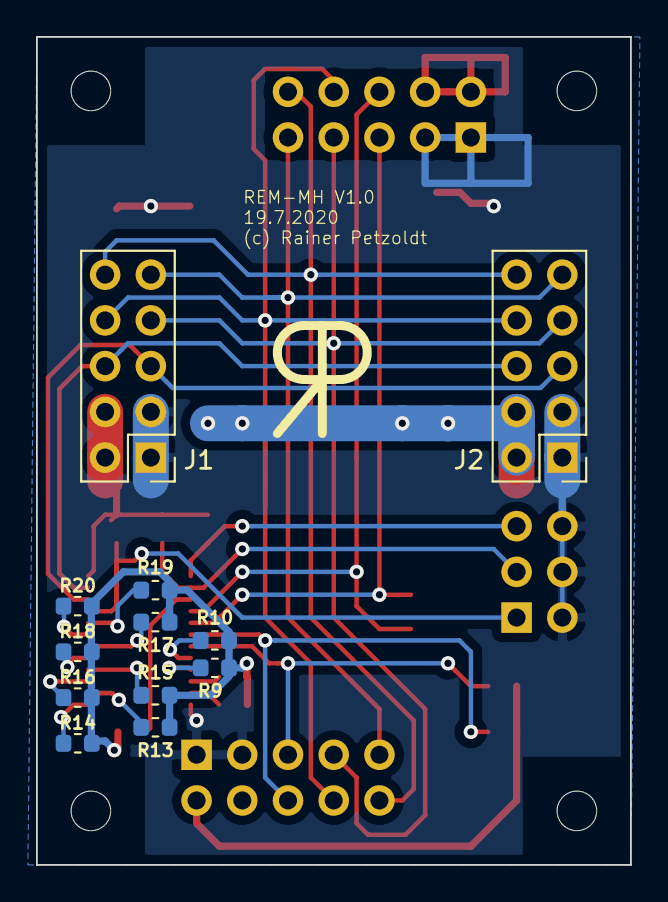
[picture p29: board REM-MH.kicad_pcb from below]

Board: 2 copper layers, 33.0 x 46.0 mm, 36 parts (13 on the bottom side), 28 nets.

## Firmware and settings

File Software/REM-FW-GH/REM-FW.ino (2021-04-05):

/*
	Name:          REM-FW.ino
	Description:   Firmware for REM Project
	Project:       REM  (Rainer's Energy Mesaurement) power measurement in AC networks
	Created:	   20.06.2020
	Last modified: 05.04.2021
	Author:        Rainer Petzoldt  R.Petzoldt@web.de
*/


#include "RemMqtt.h"
#include "Zeit.h"
#include "HtmlServer.h"
#include "ADE7816IData.h"
#include "ADE7816Data.h"
#include "RemMM.h"
#include "TCA9548a.h"
#include "Logger.h"
#include <esp32-hal-log.h>
#include "RemPara.h"

#define USEMQTT

// Unterscheidung Wifi oder Ethernet über ein globales define  (Wifi Funktionen nicht alle getestet)
#ifdef USE_ETH
#include "NetworkEthernet.h"
NetworkEthernetClass network;
#else
#include "NetworkWifi.h"
NetworkWiFiClass network("my_ssid", "my_password");   // wird später mit denen aus RepPara.json überschrieben
#endif

int counter = 0;							// Schleifenzähler
unsigned long t1, t2;						// Zeiten
unsigned long lastTimeSent = 0;

HtmlServerClass htmlServer;

#pragma region prototypes
// Prototypen
void mqttHandleNewData(RemMMClass *remMMData);
void handleInput(char c);  // siehe unten
#pragma endregion



void setup()
{
	Serial.begin(115200);
	Logger.printf("************START*********************\n");
	remPara.init();											// Parameter aus SPIFFS einlesen
	remPara.show();											// Anzeigen der Parameter 
	IPAddress defaultIp = IPAddress(192, 168, 22, 254);		// IP greift nur falls kein DHCP und kein Configfile im Spiffs
	defaultIp.fromString(remPara.defaultIp);	            // default IP aus Parametern lesen
	Serial.printf("defaultIp="); 	Serial.println(defaultIp);
#ifndef USE_ETH
	network.SetPassword(remPara.wifi_ssid.c_str(), remPara.wifi_password.c_str());  // Passwort aus Konfigfile verwenden
#endif
	network.init(defaultIp);								// Netzwerk initialisieren
	Logger.info("Init OTA...");
	network.otaInit(RemMMClass::saveAllEnergyCounter);      // OTA initialisierern, vor Update die Energiezähler sichern
	Logger.info("Init NTP...");
	Zeit.init(network.getNtpServer());						// Zeitserver initialisierern
	lastTimeSent = millis() - Zeit.timeClient->getSeconds() * 1000 - Zeit.timeClient->getMilliseconds();
	Logger.info("Init Logger...");
	Logger.init();											// nur für Logging über Telnet erforderlich

	pinMode(PWR_SWITCH, OUTPUT);							// Pin für Power-Schalter festlegen
	RemMMClass::powerSwitch(true);	                        // Strom einschalten

	RemMMClass::initModules();								// RemMM Module initialisierern

#ifdef USEMQTT
	RemMqtt.init(&network.client, remPara);					// MQTT initialisierern
#endif
	htmlServer.init();										// HTML Server initialisierern
	bool restored = RemMMClass::restoreAllEnergyCounter();	// prüfen ob gespeicherte Energiezähler vorhanden sind, diese auslesen
	RemMqtt.getLastEnergyCounter();							// Versuchen die Energiezähler per MQTT zu restaurierern

	Logger.info("End setup() ***********************************\n");
	Logger.loglevel = LOGLEVEL_INFO;						// Loglevel auf INFO reduzierern
}


void loop()
{
	t1 = millis();								// Startzeit merken
	counter++;

	// neue Daten behandeln
	bool hasNewData = RemMMClass::handleAllNewData(mqttHandleNewData);	// hier wird auf neue Daten geprüft und dann mqttHandleNewData aufgerufen


#ifdef USEMQTT
	if (millis() - lastTimeSent >= 60000) // alle 60s Zeit per MQTT senden
	{
		lastTimeSent = millis() - Zeit.timeClient->getSeconds() * 1000 - Zeit.timeClient->getMilliseconds();  // immer volle Minute senden
		RemMqtt.sendTime();	// falls notwendig
	}
	if (counter % 100 == 0) // alle 10s MQTT Connection prüfen
	{
		RemMqtt.reconnect();	// falls notwendig
	}
	RemMqtt.handleClient(); 	// behandelt die MQTT Telegramme (Empfang)  noch nicht implementiert
#endif

	Zeit.handleTime();

	//  warten bis 100ms um sind seit start, dabei OTA, HTML-Server und Eingaben behandeln
	unsigned long t3 = millis();
	for (int w = 0; w < 100; w++)  // maximal 100 mal
	{
		network.handleUpdater();
		htmlServer.handleClient();
		Logger.handleClients();

		int c = Serial.read();
		if (c != -1) handleInput(c);

		t2 = millis();
		unsigned long dt = t2 - t1;
		// bei overflow wird sofort ein break ausgelöst, d.h. alle 50 Tage ist die Schleife 1 mal nur 30 ms lang -> kein Problem
		if (dt >= 100) break;	// wenn 100ms seit Loop-Start dann beenden

		delay(1);
	}
	Logger.debug("Schleifenzeiten: Arbeit=%d ms  Warten+HTML=%d ms   %d  %d  %d", t3 - t1, t2 - t3, t1, t3, t2);

}


//
// Diese Funktion wird aufgerufen wenn neue Daten eingetroffen sind
// sie informiert alle die benachrichtigt werden müssen
//
void mqttHandleNewData(RemMMClass *remMMData)
{
	//Logger.info("%d Messungen in %s", remMMData->ade7816.data.noOfMeasurements, remMMData->name);
#ifdef USEMQTT
	RemMqtt.mqttHandleNewData(remMMData);		// neue Daten per MQTT senden
#endif
    // hier können weitere Handler ergänzt werden ...						
}

//
// Behandlung von Debugbefehlen die über die serielle Schnittstelle eingehen
//
void handleInput(char c)
{
	String charStr = " ";
	int idx = 0;
	Logger.info("SerialIn: %c %x ", c, c);
	switch (c)
	{
	case 'c':
		Logger.loglevel = 5;
		Logger.printf("Loglevel auf CRITICAL gesetzt\n");
		break;
	case 'e':
		Logger.loglevel = 4;
		Logger.printf("Loglevel auf ERROR gesetzt\n");
		break;
	case 'w':
		Logger.loglevel = 3;
		Logger.printf("Loglevel auf WARNING gesetzt\n");
		break;
	case 'i':
		Logger.loglevel = 2;
		Logger.printf("Loglevel auf INFO gesetzt\n");
		break;
	case 'd':
		Logger.loglevel = 1;
		Logger.printf("Loglevel auf DEBUG gesetzt\n");
		break;
	case 'r':
		Logger.printf("Reset von welchem Modul? Idx=");
		charStr = Serial.readString();
		idx = charStr.toInt();
		Logger.printf("%d\nReset von Modul? %s\n", idx, RemMMClass::remMM[idx]->name);
		RemMMClass::remMM[idx]->resetAde7816();
		break;
	case 's':
		Logger.printf("Befehl s = saveEnergyCounter()\n");
		RemMMClass::saveAllEnergyCounter();
		break;
	case 'R':
		Logger.printf("Befehl s = saveEnergyCounter()\n");
		RemMMClass::restoreAllEnergyCounter();
		break;
	case 'I':
		Logger.printf("Show Info:\n");
		Logger.printf("   %d REMMM Module gefunden\n", RemMMClass::anzModules);
		for (size_t i = 0; i < RemMMClass::anzModules; i++)
		{
			Logger.printf("      %02d %s\n", i, RemMMClass::remMM[i]->name);
		}
		remPara.show();
		break;
	default:
		break;
	}
}

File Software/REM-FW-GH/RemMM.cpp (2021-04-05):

/*
	Name:        RemMM.cpp
	Description: Handler für REM-MM modul
	Project:     REM  (Rainer's Energy Measurement) power measurement in AC networks
	Created:	 03.07.2020
	Author:      Rainer Petzoldt  R.Petzoldt@web.de
*/

#include "RemMM.h"
#include "RemPara.h"
#include <Wire.h>
#include "TCA9548a.h"
#include "Logger.h"
#include "Zeit.h"
#include "SPIFFS.h"
#include "ArduinoJson.h"    // https://arduinojson.org/

#define ade7816Addr 0x38
#define MCPADR 0x20
#define MCP_IODIR 0
#define MCP_GPIO 9
#define MCP_GPPU 6
#define MCP_LED 0
#define MCP_TASTER 1
#define MCP_RESET 0x80

int RemMMClass::anzModules = 0;
//int RemMMClass::anzZyklen = 5;
int RemMMClass::allRemMmAdrList[MAXREMMMMODULES];
RemMMClass *RemMMClass::remMM[MAXREMMMMODULES];
long RemMMClass::startTime = 1234;
int RemMMClass::selectedAdr = -1;

RemMMClass::RemMMClass(int adr)
{
	_adr = adr;
	Logger.debug("RemMMClass(%X) ctor",adr);
	sprintf(name, "REMMM%03X", _adr);  // hier wird der Name generiert
	init();
}

void RemMMClass::init()
{
	Logger.debug("RemMMClass::init()  name=%s",name);
	int lastSelect = select();
	setMcpRegister(MCP_GPIO, 0x80);  // LED aus, kein Reset
	setMcpRegister(MCP_GPPU, 0x02);  // pullup resistor bei Taster
	setMcpRegister(MCP_IODIR, 0x7E);  // IO Dir setzen
	ade7816 = ADE7816_I2C();
	ade7816.init(false,name);
	deselect(lastSelect);
}

bool RemMMClass::handleAllNewData(void(*func_ptr)(RemMMClass * data_ptr))
{
	bool hasNewData = false;
	for (size_t module = 0; module < anzModules; module++)
	{
		bool newData = remMM[module]->handleNewData(func_ptr);
		hasNewData |= newData;
		if (newData) Logger.debug("%s has new Data", remMM[module]->name);
	}
	return hasNewData;
}

bool RemMMClass::handleNewData(void(*func_ptr)(RemMMClass * data_ptr))
{
	bool hasNewData = false;
	int lastSelect = select();
	hasNewData |= ade7816.hasNewValues(); 
	if (hasNewData)							// gibts neue Daten?
	{
		setLed(false);
		ade7816.handleNewData();			// Daten aus dem Chip auslesen
		func_ptr(this);						// und an alle melden die es interessiert
		setLed(true);
	}
	handleIO();								// Taste abfragen

	deselect(lastSelect);
	
	return hasNewData;
}

bool RemMMClass::handleIO()
{
	// todo: Taster abfragen, wird nur jede 2. mal erkannt, warum?
	byte io = getMcpRegister(MCP_GPIO);
	//Logger.debug("%2X", io);
	bool tasteNew = !( io & 0x02);
	if (taste != tasteNew)
	{
		taste = tasteNew;
		if (taste) Logger.info("Taste gedrueckt an Modul MM %X", _adr);
		else Logger.info("Taste losgelassen an Modul MM %X", _adr);
	}

}

void RemMMClass::setMcpRegister(byte adr, byte val)
{
	//select();  // todo  generell anders behandeln
	Wire.beginTransmission(MCPADR);
	Wire.write(adr);
	Wire.write(val);
	Wire.endTransmission();
	//deselect();  // alten Zustand wiederherstellen
}

byte RemMMClass::getMcpRegister(byte adr)
{
	int lastSelect = select();
	Wire.beginTransmission(MCPADR);
	Wire.write(adr);
	Wire.endTransmission();
	Wire.requestFrom(MCPADR, 1);
	byte ioreg = Wire.read();
	deselect(lastSelect);
	//Logger.debug("   %X %d", ioreg, ioreg);
	//Serial.println(ioreg, 2);
	return ioreg;
}

bool RemMMClass::setLed(bool on)
{
	// nur LED Port
	int lastAdr = select();  
	if (on)	setMcpRegister(MCP_GPIO, 0x1 | MCP_RESET);   //  80 = kein Reset
	else 	setMcpRegister(MCP_GPIO, 0x0 | MCP_RESET);   //  80 = kein Reset
	deselect(lastAdr);
}

bool RemMMClass::resetAde7816()
{
	Logger.warning("resetADE7816");
	// erst resetpin für 10ms auf low ziehen
	setMcpRegister(MCP_GPIO, 0x00);	// reset und LED an
	delay(10);
	setMcpRegister(MCP_GPIO, 0x81);  // reset ende und LED aus
	// dann neu initialisieren
	init();
}


int RemMMClass::select()
{ 
	if (_adr == selectedAdr) return _adr;    // Adr war schon eingestellt
	int lastAdr = selectedAdr;
	//Logger.debug("RemMMClass::select _adr=%04X", _adr);
	TCA9548a::tcaSelect(selectedAdr >> 4, -1);	// alte Adr abwählen
	TCA9548a::tcaSelect(_adr >> 4, _adr & 0x0F); // neue Adr auswählen
	selectedAdr = _adr;
	return lastAdr;	// alte adr zurückgeben
}

void RemMMClass::deselect(int newAdr=-1)
{
	if (newAdr == selectedAdr) return ;    // Adr war schon eingestellt
	//Logger.debug("RemMMClass::deselect(%X)",newAdr);

	TCA9548a::tcaSelect(selectedAdr >> 4, -1);	// alte Adr abwählen 
	if (newAdr !=-1) TCA9548a::tcaSelect(newAdr >> 4, newAdr & 0x0F);  // neue Adr einstellen
	selectedAdr = newAdr;
}


//  -------------Current---------------------------------

// Setzt die IxGain Werte auf den angegebenen Wert
// die Werte werden in Parameter und im ADE7816 gesetzt
// die Werte werden nicht ins Flash geschrieben
void RemMMClass::setCurrentGain(int sollGain)  
{
	Logger.debug("RemMMClass::setCurrentGain(%d)", sollGain);
	for (size_t i = 0; i < 6; i++)
	{
		int lastAdr = select();
		ade7816.setIxGain(i, sollGain);
		deselect(lastAdr);
	}
}


// Setzt die IxRMSOS Werte auf den angegebenen Wert
// die Werte werden in Parameter und im ADE7816 gesetzt
// die Werte werden nicht ins Flash geschrieben
void RemMMClass::setCurrentOffset(int sollOffset)
{
	Logger.debug("RemMMClass::setCurrentOffset(%d)", sollOffset);
	for (size_t i = 0; i < 6; i++)
	{
		int lastAdr = select();
		ade7816.setIxRMSOS(i, sollOffset);
		deselect(lastAdr);
	}
}




// Bestimmt die IxGain Werte
// setzt IxGain so, dass der Strom sollCurrent gemessen wird
// die Werte werden in Parameter und im ADE7816 gesetzt
// die Werte werden nicht ins Flash geschrieben
void RemMMClass::kalibCurrentGain(double sollCurrent)  // in Ampere
{
	Logger.debug("RemMMClass::kalibCurrentGain(%f)", sollCurrent);
	// bestimmen des RawCurent
	for (size_t i = 0; i < 6; i++)
	{
		double sollCurrentRawD = sollCurrent / ade7816.ScaleCurrentRawToAmpereWithGain(i);
		int sollCurrentRaw = (int)sollCurrentRawD;
		Logger.debug("sollCurrentRaw = %d  (%X)", sollCurrentRaw, sollCurrentRaw);
		// hier wird der aktuell eingestellete Gain herausgerechnet  (nicht der Vorverstärker, der ist schon 3 Zeilen weiter oben berücksichtigt)
		int currentRaw = ade7816.data.chan[i].currentRaw; // nur debug
		double korrFaktor = (double)ade7816.parameter.chan[i].IxGAIN / (1 << 23);
		if ((korrFaktor > 1.0) | (korrFaktor < -1.0))
		{
			Logger.warning("kalibCurrentGain: korrFaktor=%f ist nicht plausibel, wird auf 0 gesetzt", korrFaktor);
			korrFaktor = 0.0;
		}
		korrFaktor += 1.0;
		int currentRawCorrected = (int)((double)ade7816.data.chan[i].currentRaw / korrFaktor);
		Logger.debug("currentRaw=%d  korrFaktor=%f  -> Korrected=%d", currentRaw, korrFaktor, currentRawCorrected);

		int lastAdr = select();
		ade7816.calibIxGain(i, sollCurrentRaw, currentRawCorrected);
		deselect(lastAdr);
	}
}
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

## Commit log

2020-09-23 Platinen veröffentlicht
    [ACDC.FCStd, ACDC.scad, ADE7816_Phase_Calibration_Formula.xls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]
2020-09-23 3d Daten der Gehäuse veröffentlicht
    [REM-C-Deckel_V1.1.stl, REM-C-Geh.scad, REM-C-Oberteil_V1.1.stl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]

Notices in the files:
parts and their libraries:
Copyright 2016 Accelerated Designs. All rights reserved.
